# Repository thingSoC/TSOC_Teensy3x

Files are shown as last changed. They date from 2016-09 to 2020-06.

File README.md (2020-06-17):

# TSOC_Teensy3x

The **TSOC_Teensy3x** is an adapter board for the excellent [Teensy Development Board](https://www.pjrc.com/teensy/) from [PJRC](https://www.pjrc.com/).

The **TSOC_Teensy3x** allows you to connect [thingSoC](http://thingsoc.github.io/), [Mikrobus](http://www.mikroe.com/mikrobus/), 
and/or [Grove System](http://www.seeedstudio.com/blog/2016/03/09/tutorial-intro-to-grove-connectors-for-arduinoraspberry-pi-projects/) 
Modules all at the same time, either standalone, or with any other thingSoC Processor or Radio module.
This gives you maximum flexiblity for sensor and actuator selection and reuse. 

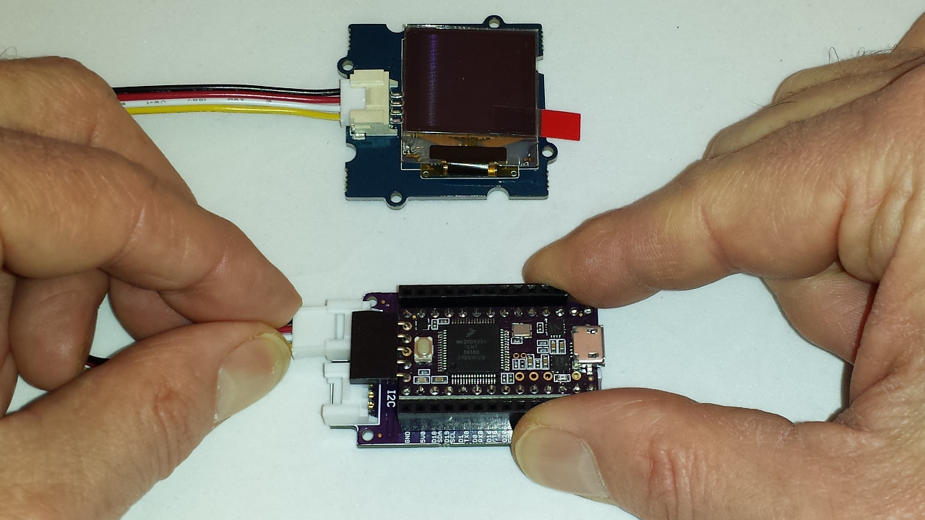
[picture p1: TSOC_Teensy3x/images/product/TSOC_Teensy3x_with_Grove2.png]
thingSoC TSOC_TEENSY3X
[TSOC_TEENSY3X](https://github.com/thingSoC/TSOC_TEENSY3X)

The thingSoC "Grovey Series" was designed as "Everyday Electronics", a no-frills, low cost, approach to modular embedded product design.
thingSoC boards are similar in size to most break-out-boards (BOBs), but feature a standardized stacking pinout, as well as an I2C metadata store (EEPROM)
to indicate what peripherals are installed.

---------------------------------------

## TSOC_TEENSY3X Application Pictures

In this example, we use the [Grovey_I2CHUB](https://github.com/thingSoC/TSOC_GROVEY_I2CHUB) with the [Teensy3.x Adapter](https://github.com/thingSoC/TSOC_Teensy3x)
to support a Grove 16x2 LCD panel.

Since the Grove 16x2 LCD panel is a 5V peripheral, the [Grovey_I2CHUB](https://github.com/thingSoC/TSOC_GROVEY_I2CHUB) performs the voltage level translation
necessary to go from the 3.3V Teensy3.x processor to the 5V LCD controller. The [Teensy3.x Adapter](https://github.com/thingSoC/TSOC_Teensy3x) also has an I2C output jack, but it is at a 3.3V level,
and so, the [Grovey_I2CHUB](https://github.com/thingSoC/TSOC_GROVEY_I2CHUB) is necessary to convert to 5V I2C outputs.

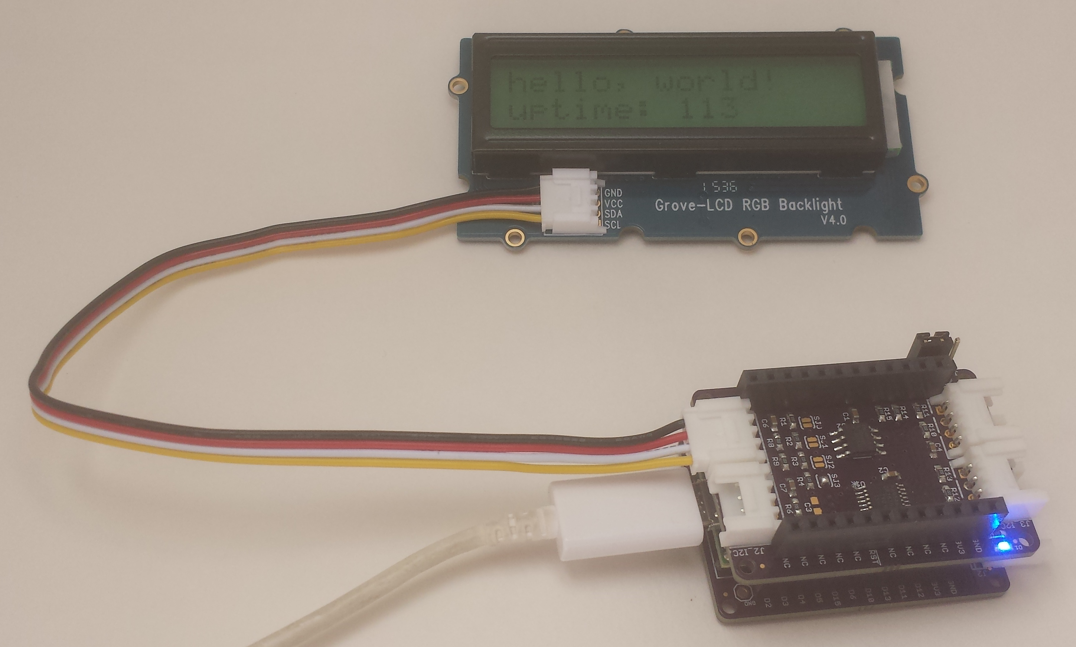
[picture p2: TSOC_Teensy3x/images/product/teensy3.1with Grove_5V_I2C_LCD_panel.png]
thingSoC TSOC_TEENSY3X
[*TSOC_TEENSY3X*](https://github.com/thingSoC/TSOC_TEENSY3X)

---------------------------------------

## TSOC_Teensy3x with Mikrobus "Click" peripherals

The [Teensy3.x Adapter](https://github.com/thingSoC/TSOC_Teensy3x) also allows you to plug in [Mikrobus](http://www.mikroe.com/mikrobus/) 
peripherals and ["Click Modules"](http://www.mikroe.com/click/), and use these along with the 
[Grove System](http://www.seeedstudio.com/blog/2016/03/09/tutorial-intro-to-grove-connectors-for-arduinoraspberry-pi-projects/) modules. 

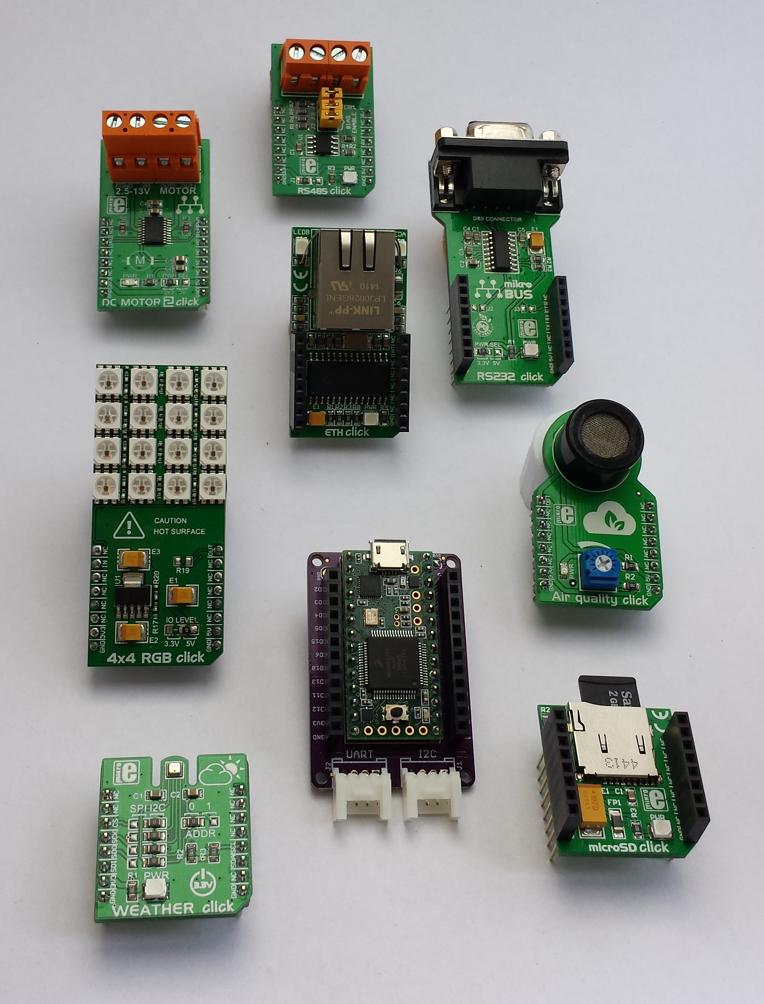
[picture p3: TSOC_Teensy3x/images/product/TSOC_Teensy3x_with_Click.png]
thingSoC TSOC_TEENSY3X
[*TSOC_TEENSY3X*](https://github.com/thingSoC/TSOC_TEENSY3X)

---------------------------------------

## TSOC_TEENSY3X Arduino Sketch Examples

Under the Arduino "examples" directory are many Arduino IDE examples for using the Teensy board with Arduino IDE,
provided by [PJRC](https://www.pjrc.com/). Paul provides [setup and installation instructions](https://www.pjrc.com/teensy/tutorial.html) for the Teensy.
What the **TSOC_Teensy3x** adaptor board provides is an easy "plug-n-play" way to connect many different peripherals to the Teensy.

---------------------------------------

## TSOC_TEENSY3X Status <a name="TSOC_TEENSY3X_status"/>

**09/02/2016:** 
Revision 1.0 - Initial Layout - SPI PINS D11/D12 reversed!
Revision 2.0 - Fix SPI Pins, add Analog I/O

---------------------------------------
## TSOC_TEENSY3X Images

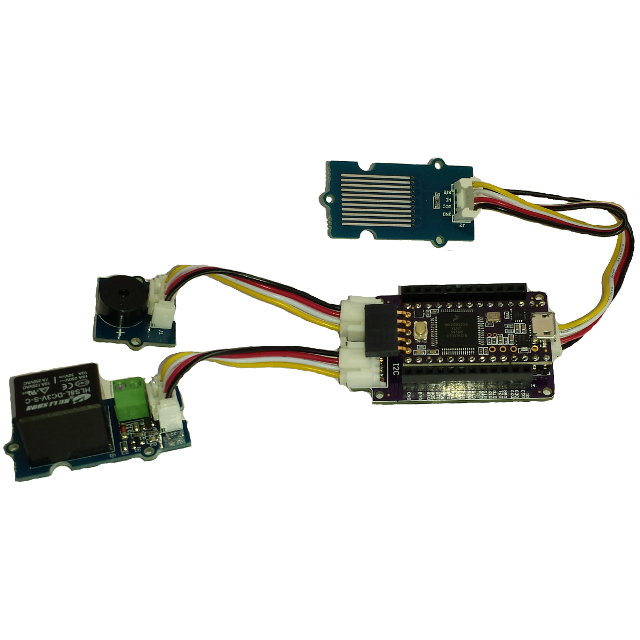
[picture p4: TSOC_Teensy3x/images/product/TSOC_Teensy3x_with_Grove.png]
thingSoC TSOC_TEENSY3X
[TSOC_TEENSY3X](https://github.com/thingSoC/TSOC_TEENSY3X)

---------------------------------------

## TSOC_TEENSY3X Documentation Index <a name="TSOC_TEENSY3X_documentation_index"/>

[TSOC_TEENSY3X Project](https://github.com/thingSoC/TSOC_Teensy3x)

[TSOC_TEENSY3X Hardware](https://github.com/thingSoC/TSOC_Teensy3x/tree/master/TSOC_Teensy3x/hardware)

---------------------------------------

## thingSoC Documentation Index <a name="thingSoC_documentation_index"/>

[thingSoC Organization Website](http://thingSoC.github.io)

[thingSoC FAQ - Frequently Asked Questions](http://thingsoc.github.io/support/faq.html)

---------------------------------------

[thingSoC 
*thingSoC*](http://thingsoc.github.io)

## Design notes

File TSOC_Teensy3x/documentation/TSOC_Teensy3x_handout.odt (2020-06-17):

thingSoC Teensy3x Board

Thank you for purchasing a TSOC_Teensy3x board!
Please see the Getting Started Guide at :
https://github.com/thingSoC/TSOC_Teensy3x (https://github.com/thingSoC/TSOC_NEOLED)
It has complete instructions and examples to download.

thingSoC Teensy3x Board

Thank you for purchasing a TSOC_Teensy3x board!
Please see the Getting Started Guide at :
https://github.com/thingSoC/TSOC_Teensy3x (https://github.com/thingSoC/TSOC_NEOLED)
It has complete instructions and examples to download.

thingSoC Teensy3x Board

Thank you for purchasing a TSOC_Teensy3x board!
Please see the Getting Started Guide at :
https://github.com/thingSoC/TSOC_Teensy3x (https://github.com/thingSoC/TSOC_NEOLED)
It has complete instructions and examples to download.

thingSoC Teensy3x Board

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

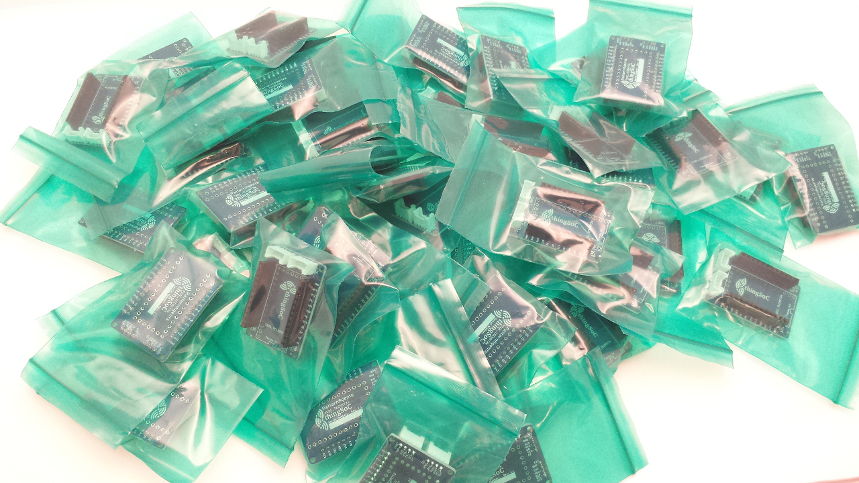
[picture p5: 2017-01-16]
TSOC_Teensy3x/images/product/teensy3x_seeed.jpg

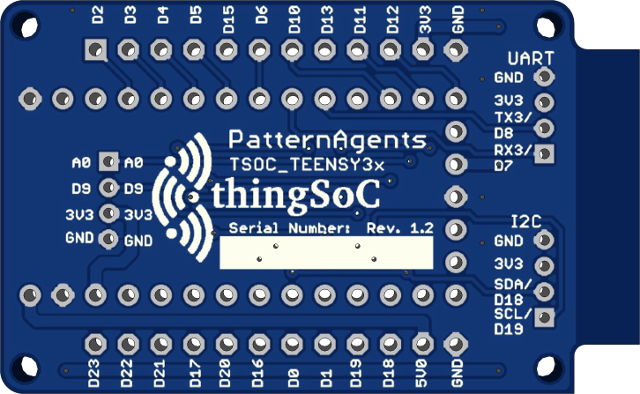
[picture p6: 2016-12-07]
TSOC_Teensy3x/images/TSOC_Teensy3x_bot.png

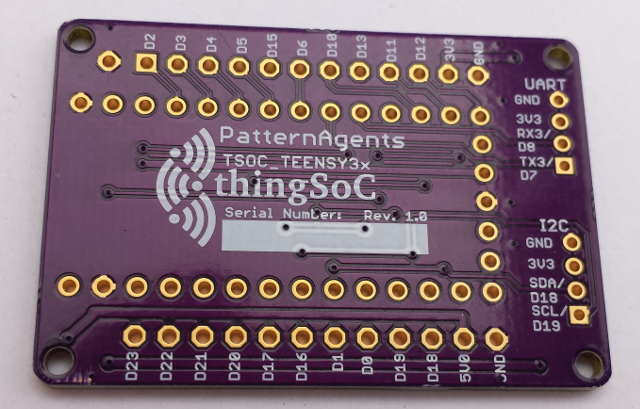
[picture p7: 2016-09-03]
TSOC_Teensy3x/images/product/TSOC_Teensy3x_pcb_bot.png

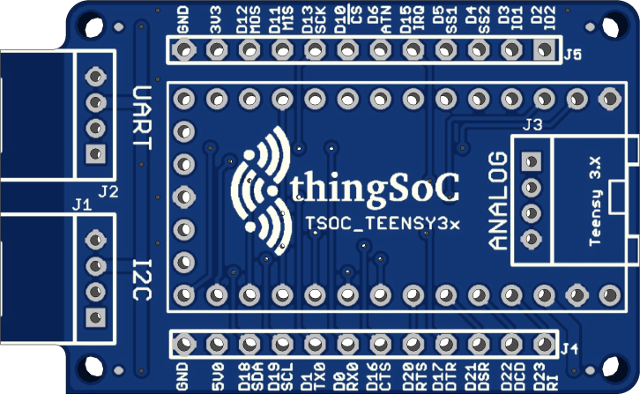
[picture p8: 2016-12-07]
TSOC_Teensy3x/images/TSOC_Teensy3x_top.png

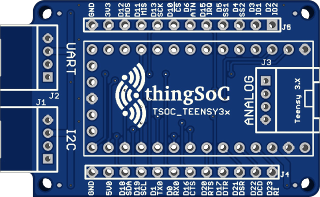
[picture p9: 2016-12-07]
TSOC_Teensy3x/images/TSOC_Teensy3x.png

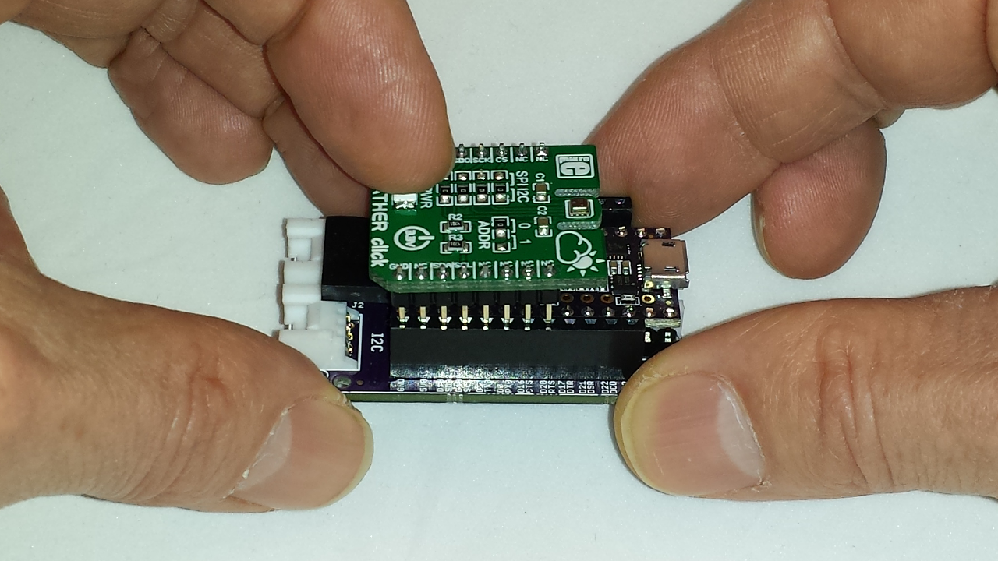
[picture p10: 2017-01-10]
TSOC_Teensy3x/images/product/TSOC_Teensy3x_with_Click2.png

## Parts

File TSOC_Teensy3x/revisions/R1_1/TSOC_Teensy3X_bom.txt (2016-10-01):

Partlist exported from U:/PatternAgents/eagle/TSOC_Modules/TSOC_Teensy3x/TSOC_Teensy3x/TSOC_Teensy3X.sch at 9/3/2016 11:11:48 AM

Revision 1.1

Qty Value             Device                      Package          Parts                  Description                                                                                                                                    
2   4P-2.0            GROVE-CONNECTOR-DIP(4P-2.0) HW4-2.0          J1, J2                 320110033                                                                                                                                      
2   M12               12 Pin, 2.54mm spacing,     M12              J3,J4

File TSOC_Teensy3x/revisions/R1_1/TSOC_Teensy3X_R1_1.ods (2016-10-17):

Qty | Value | Device | Package | Parts | Description | BOM | Seeed# | Digikey# | Digikey $/ea | MOQ | # have
1 | TSOC-PCB-SINGLE | TSOC-PCB-SINGLE | TSOC-BB-BRD-DIM | PCB | thingSoC PCB Outlines | PCB |  |  | $4.00
2 | F13X1 |  | F13x1 |  | Teensy (13) Pin Socket | OPTIONAL
2 | F12X1 | CONN HEADER FEM 12POS.1' SGL TIN | F12X1 |  | ThingSoC (12) Pin Socket | OPTIONAL |  | S6100-ND | 0.98 | 1 | 12
2 | 4P-2.0 | GROVE-CONNECTOR-DIP(4P-2.0) | HW4-2.0 | J1, J2 | Grove (4) Pin Socket | OPTIONAL | 320110033 |  | $0.15
1 | JMP-2-NC | JMP-2-NC | JMP-2-NC | 3V3 | Two Terminal Jumper - Normally Closed | EXCLUDE
1 |  | WPAD-1-PTH | WPAD-1-PTH-2.54 | GND | Wire Pad - Single | EXCLUDE

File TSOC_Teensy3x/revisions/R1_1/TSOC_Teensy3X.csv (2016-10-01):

Qty | Value | Device | Package | Parts | Description | BOM | VALUE
1 |  | WPAD-1-PTH | WPAD-1-PTH-2.54 | GND | Wire Pad - Single | EXCLUDE
2 | 4P-2.0 | GROVE-CONNECTOR-DIP(4P-2.0) | HW4-2.0 | J1, J2 | 320110033 |  | 4P-2.0
4 | FIDUCIALUFIDUCIAL | FIDUCIALUFIDUCIAL | MICRO-FIDUCIAL | FID1, FID2, FID3, FID4 | Fiducial Alignment Points
1 | JMP-2-NC | JMP-2-NC | JMP-2-NC | 3V3 | Two Terminal Jumper - Normally Closed | EXCLUDE
1 | TEENSY_3.0_BASIC | TEENSY_3.0_BASIC | TEENSY_3.0_BASIC | TEENSY | Basic Teensy 3.0 with none of the 'inner' pins enabled. See '+4', 'AllAnalogPins, and 'AllPins' packages for additional pin holes, as needed."
1 | TSOC-24-BB | TSOC-24-BB | TSOC-BB-S24 | TSOC | thingSoC Twenty-Four(24) Pin Socket
1 | TSOC-LOGO-LRG | TSOC-LOGO-LRG | TSOC-LOGO-LRG | U$5 | thingSoC Logo
1 | TSOC-PCB-SINGLE | TSOC-PCB-SINGLE | TSOC-BB-BRD-DIM | U$2 | thingSoC PCB Outlines

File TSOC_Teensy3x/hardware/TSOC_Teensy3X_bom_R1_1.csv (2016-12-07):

Part/Designator | Manufacture Part Number/Seeed SKU | Quantity
J1, J2, J3 | 320110034 | 3
J4, J5 | PPTC121LFBN-RC | 2

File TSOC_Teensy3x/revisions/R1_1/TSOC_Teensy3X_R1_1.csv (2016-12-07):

Part/Designator | Manufacture Part Number/Seeed SKU | Quantity
J1, J2 | 320110033 | 2
J3, J4 | PPTC121LFBN-RC | 2

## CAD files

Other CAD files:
TSOC_Teensy3x/eagleUp/TSOC_Teensy3x.skp

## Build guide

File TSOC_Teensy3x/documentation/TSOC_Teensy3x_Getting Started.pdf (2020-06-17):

### Welcome to the thingSoC® Teensy3x Adapter Board

The TSOC_Teensy3x is an adapter for the excellent Teensy Development Board (https://www.pjrc.com/teensy/) from

### PJRC. (https://www.pjrc.com/)

The TSOC_Teensy3x allows you to connect thingSoC (http://thingsoc.github.io/) , Mikrobus (http://www.mikroe.com/mikrobus/) , and/or Grove System (http://www.seeedstudio.com/blog/2016/03/09/tutorial-intro-to-grove-connectors-for-arduinoraspberry-pi-projects/) Modules all at the same time, either standalone, or with any other thingSoC Processor or Radio module. This gives you maximum flexiblity for sensor and actuator selection and reuse.
Assembling the TSOC_Teensy3x :
If you have purchased just the adapter board by itself, you will need to do a little soldering to assemble the unit. The TSOC_Teensy3x was designed using easy to solder through-hole components, so it would be simple to assemble for even the most inexperienced user.
1) Insert male pins into the Teensy outline. MAKE SURE to put the "short side" down, into
the holes, and the "long side" of the pins on the top side, so that the Teensy has enough space to clear the "grove" connecters and solder them securely.

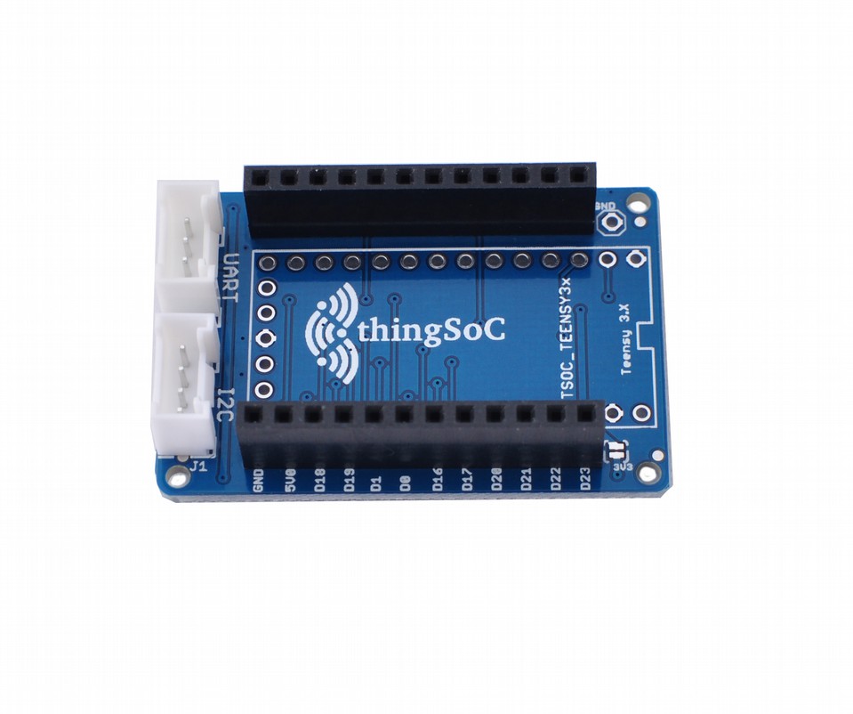
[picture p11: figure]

5) Then attach the Teensy3.2 board, and solder it securely from the top side. In the example below, we used a female connector on the end cap for access.

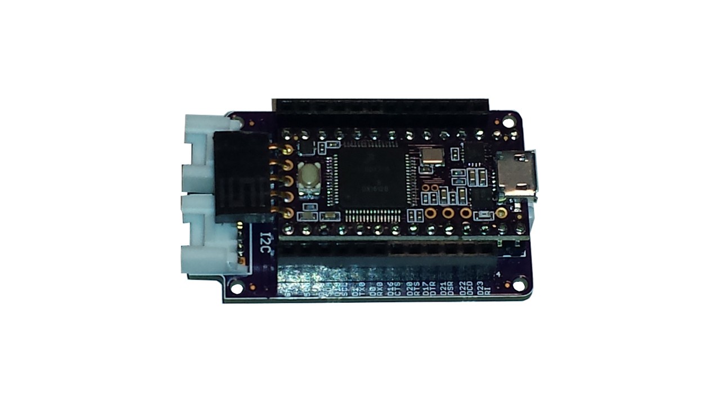
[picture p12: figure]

Download and Install Teensyduino :

Teensyduino is a software add-on for the Arduino IDE, (https://www.arduino.cc/en/Main/Software) developed for the Teensy by PJRC. (https://www.pjrc.com/teensy/td_download.html)

1) Download and install the Arduino IDE from :
https://www.arduino.cc/en/Main/Software
2) Download and install the Teensyduino package :

https://www.pjrc.com/teensy/td_download.html

3) Run the Teensyduino Installer :

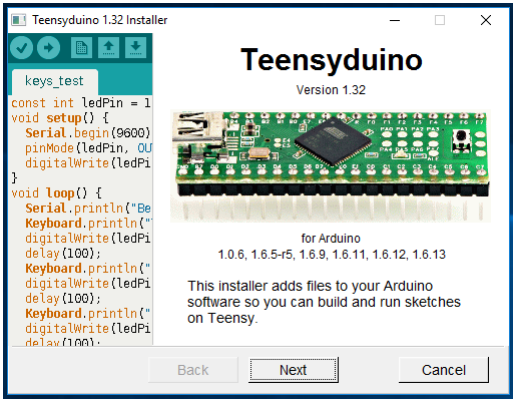
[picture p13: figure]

4) When using Arduino, be sure to select Teensy in the Tools > Boards menu.
Arduino's File > Examples menu automatically changes to show the libraries and examples for the selected board.

Getting Started :
1) Using a USB-Micro cable, plug the TSOC_Teensy3x board into your Windows, MAC, or Linux PC.
2) The drivers should be found automatically on most systems.
However if they are not, they can be downloaded from : https://www.pjrc.com/teensy/td_download.html

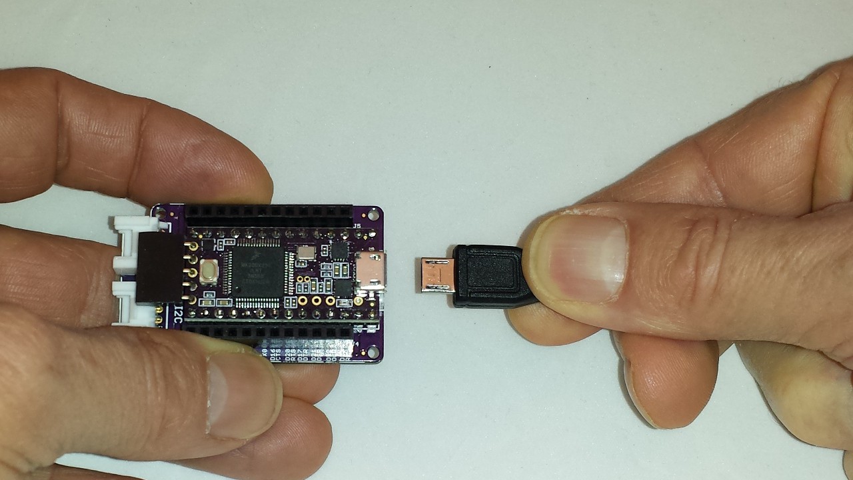
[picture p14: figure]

3) With the default firmware, when the TSOC_Teensy3x board is first connected to power, the onboard LED will begin to blink slowly.
Safe Handling Precautions :
1) Always remove/unplug all power before inserting or removing peripherals.
2) Always ground yourself by touching a ground point before handling your boards.
3) Use a static safe bag when transporting your TSOC_Teensy3x board.

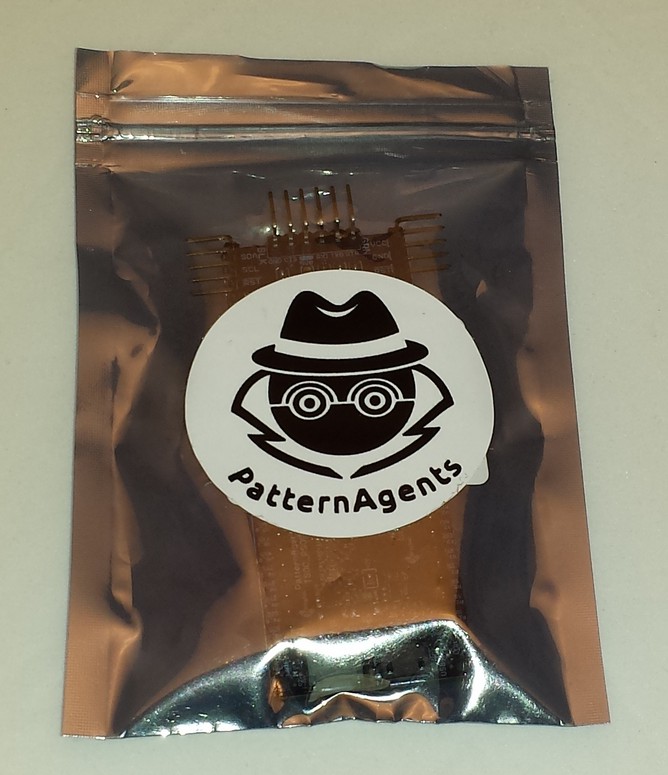
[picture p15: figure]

Supported Peripherals :
The TSOC_Teensy3x board supports thingSoC, Grove, and Mikrobus peripherals.

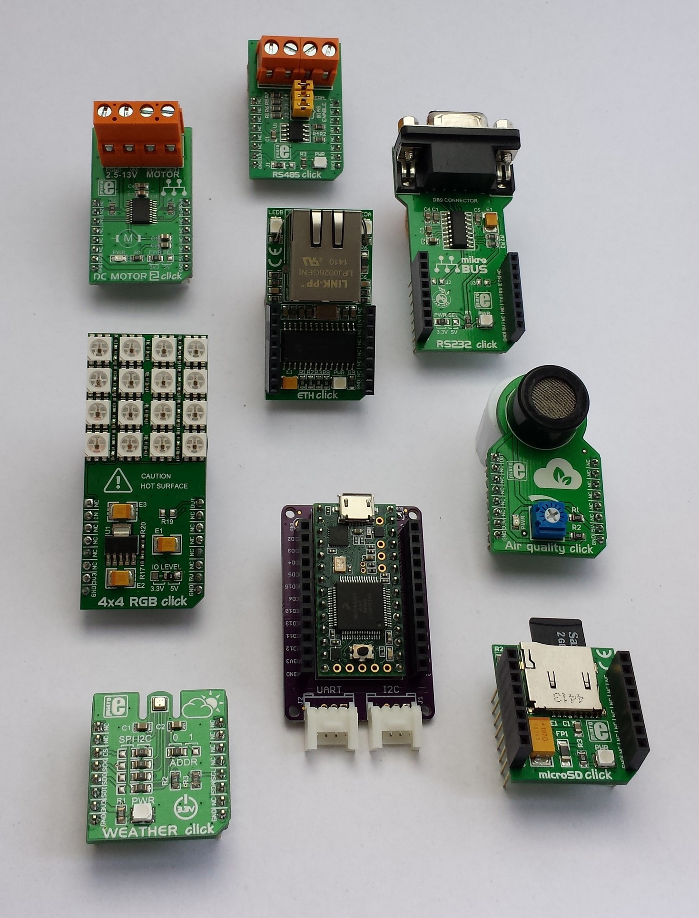
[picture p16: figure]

Attaching Mikrobus Peripherals :
1) Any 3.3 Volt compatible Mikrobus peripheral (http://download.mikroe.com/documents/standards/mikrobus/mikrobus-standard-specification-v200.pdf) may be directly connected to the TSOC_Teensy3x.
2) Make sure to align the SQUARE/CUT edges of the boards together to insure that
the polarity is correct. Push down evenly to seat the boards in the socket.
3) Note that the "stacking pins" are somewhat longer by design, and there will be some
extra space between the boards when using stacking connectors.
4) Note that Mikrobus is only sixteen (16) pins while thingSoC is twenty-four (24) pins, make sure to align the smaller Mikrobus board to the back edge of the TSOC_Teensy3x
(i.e. Ground to Ground) as shown :

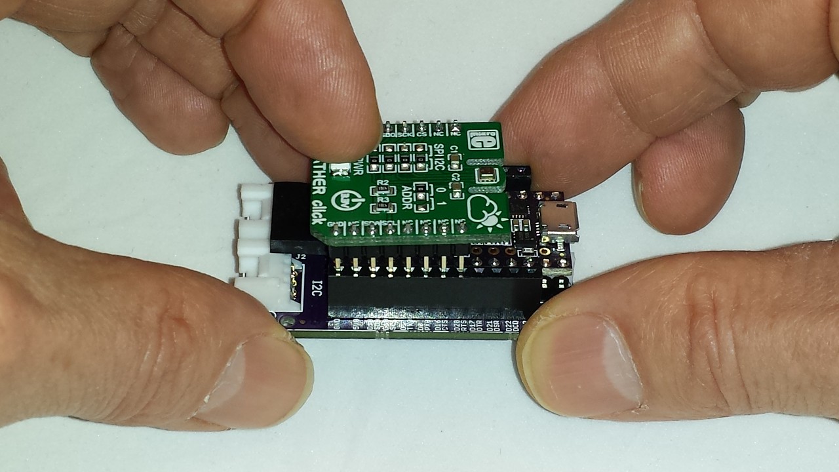
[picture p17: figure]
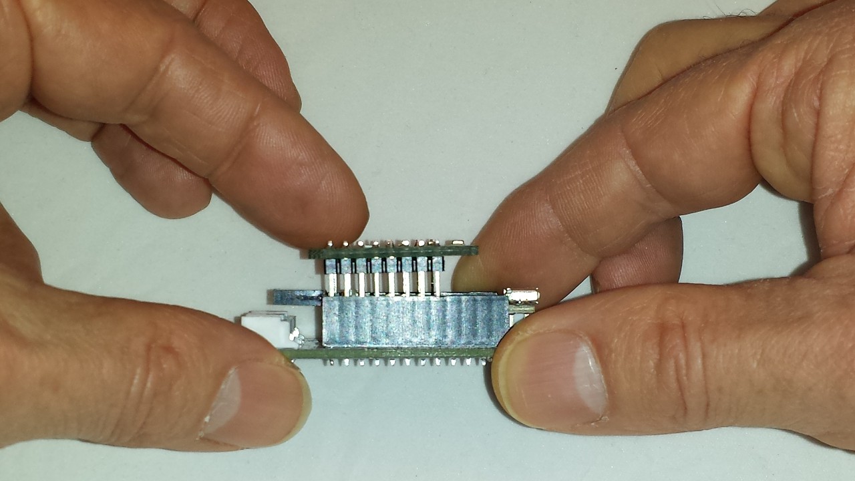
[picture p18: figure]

MikroElecktronika Click® Boards:
The TSOC_Teensy3x is compatible with most 3.3 Volt Click® boards, available at Digikey, Mouser and from Mikroelectronika direct. (https://shop.mikroe.com/click) There are already hundreds of boards available to just plug in!

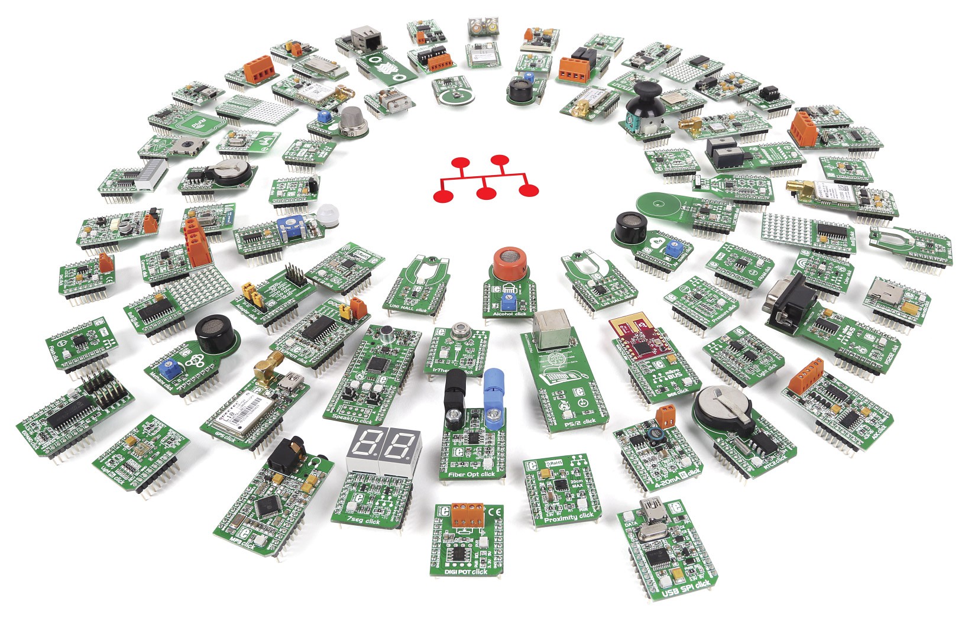
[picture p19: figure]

Attaching Grove Peripherals :
1) As shown below, there are three(3) white "Grove" connectors, and they are named, UART - (Serial #3 , using Teensy3x pins D7 and D8 )
I2C - (I2C #0, using Teensy3x pins D18 and D19 )
ANALOG - (Using Teensy3x pins A0 and D9)
Note : All of these pins are connected directly to the Teensy and are 3.3 Volt levels only.
| Do Not connect 5.0 Volt peripherals to these pins, or you may damage your Teensy! (we have the thingSoC I2C Hub, GPIO, and ADC for connecting 5.0 Volt peripherals!)

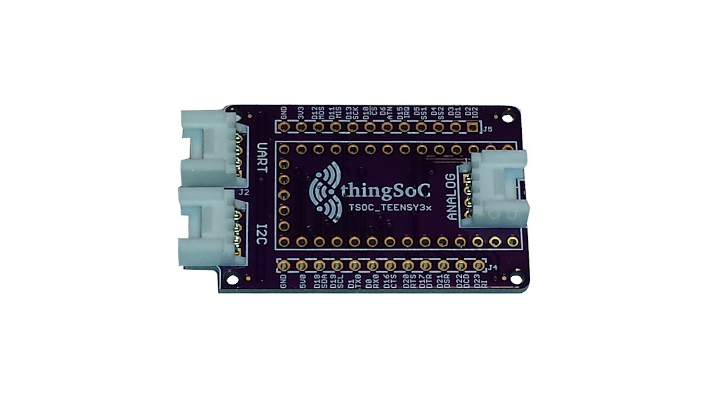
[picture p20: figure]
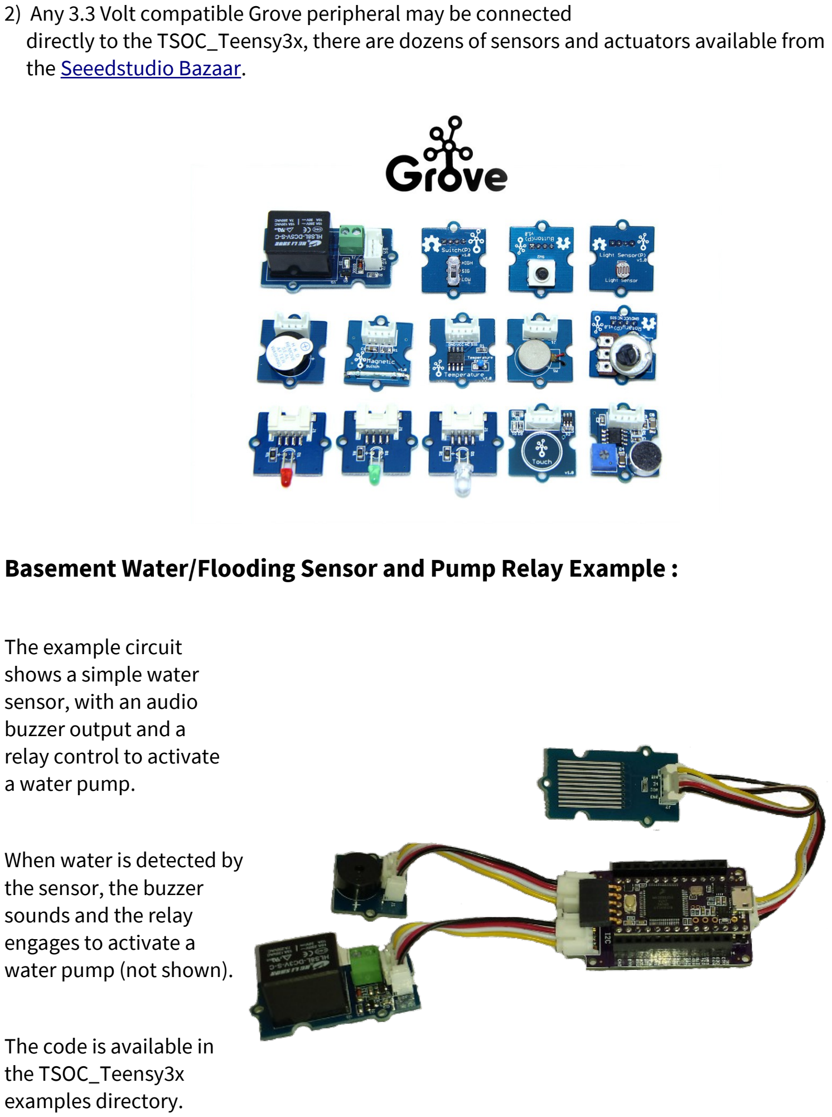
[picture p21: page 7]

2) Any 3.3 Volt compatible Grove peripheral may be connected
directly to the TSOC_Teensy3x, there are dozens of sensors and actuators available from the Seeedstudio Bazaar. (https://www.seeedstudio.com/category/Grove-c-45.html)

Basement Water/Flooding Sensor and Pump Relay Example :

The example circuit
shows a simple water
sensor, with an audio
buzzer output and a
relay control to activate
a water pump.

When water is detected by
the sensor, the buzzer
sounds and the relay
engages to activate a
water pump (not shown).

The code is available in
the TSOC_Teensy3x
examples directory.

Teensy 3.2 Features :
The TSOC_Teensy3x is a low cost, embeddable module featuring a MK20DX256VLH7 device :
- 72/96 MHZ ARM Cortex-M4F Processor (Freescale)
- USB Full-Speed Controller
- 256K Bytes Flash Memory
- 64K bytes RAM Memory
- 2048 bytes EEPROM memory
- Serial Communication (3 Ports)
- Counter/Timers/PWMs (12)
- CAN (controller area network) Controller
- I2C controllers (2)
- USER LED
- USER Pushbutton
- thingSoC Compliant Module (http://www.thingsoc.com/)
- Mikrobus Compatible Module (http://www.mikroe.com/mikrobus/)

### Top Side : (From https://www.pjrc.com/teensy/pinout.html )

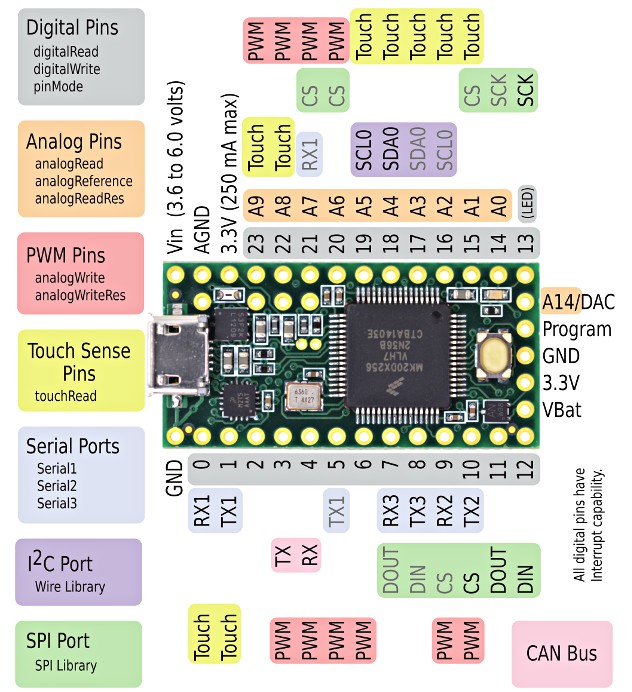
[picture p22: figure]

### Rear Side : (From https://www.pjrc.com/teensy/pinout.html )

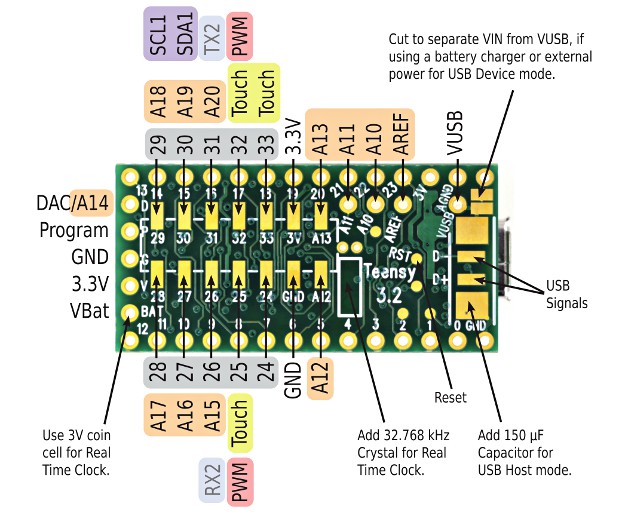
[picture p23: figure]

### thingSoC® Teensy3x Adapter Board Errata

Products Affected : Revision 1 (Blue) Boards

#1) SPI Wiring Reversed :

The initial (Rev 1) "Blue" TSOC_Teensy3x boards have the hardware SPI pins reversed, (the MISO and MOSI pins reversed). Most Arduino librarys will let you specify the SPI pins to be used explicitly, but will use software (bit-bang) SPI when you do that. Most users are able to work around this ssue. If this is a problem for your application, contact us for a Revision 2.0 board, which will be available in 3-4 weeks.

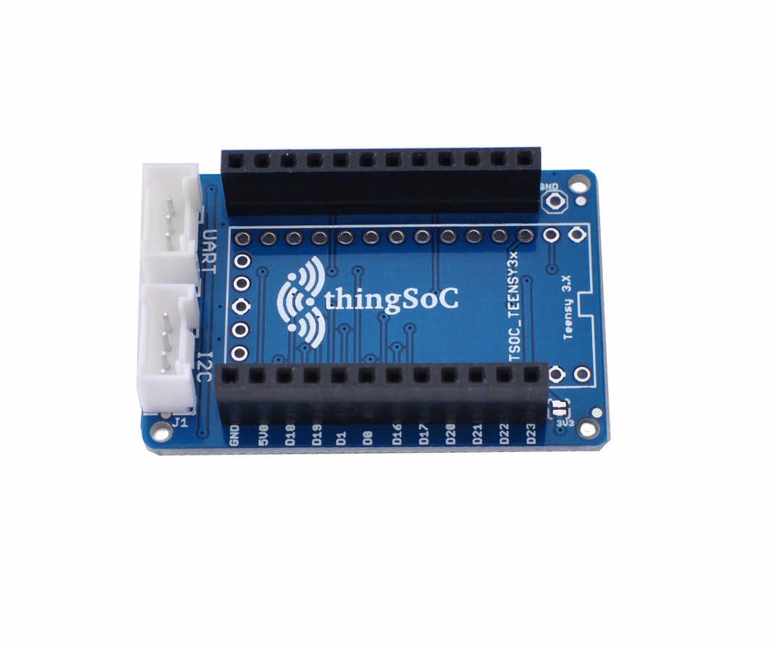
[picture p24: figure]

Revision 2.0 (Purple, Black) boards are NOT affected by Errata #1

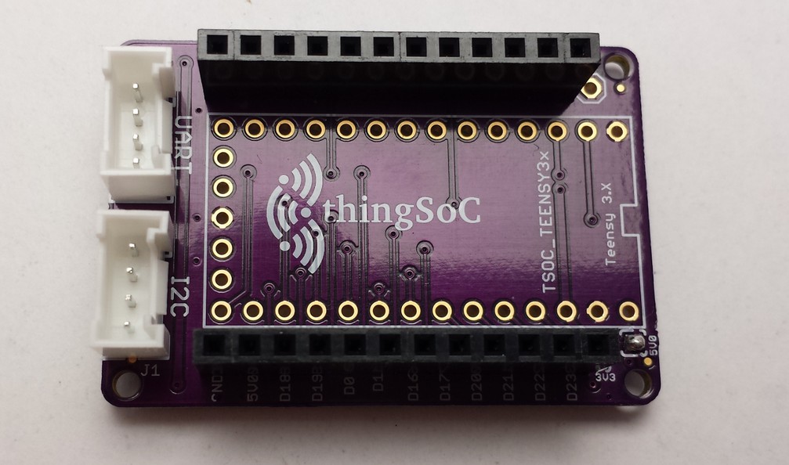
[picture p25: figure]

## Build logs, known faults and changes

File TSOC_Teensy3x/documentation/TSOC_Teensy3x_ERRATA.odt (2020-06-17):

thingSoC® Teensy3x Adapter Board Errata

The TSOC_Teensy3x is an adapter for the excellent Teensy Development Board (https://www.pjrc.com/teensy/) from PJRC (https://www.pjrc.com/).

The TSOC_Teensy3x allows you to connect thingSoC (http://thingsoc.github.io/) , Mikrobus (http://www.mikroe.com/mikrobus/) , and/or Grove System (http://www.seeedstudio.com/blog/2016/03/09/tutorial-intro-to-grove-connectors-for-arduinoraspberry-pi-projects/) Modules all at the same time, either standalone, or with any other thingSoC Processor or Radio module. This gives you maximum flexiblity for sensor and actuator selection and reuse.

Products Affected : Revision 1 (Blue) Boards

SPI Wiring Reversed :
The initial (Rev 1) "Blue" TSOC_Teensy3x boards have the hardware SPI pins reversed,
(the MISO and MOSI pins reversed). Most Arduino librarys will let you specify the
SPI pins to be used explicitly, but will use software (bit-bang) SPI when you do that.
Most users are able to work around this ssue.

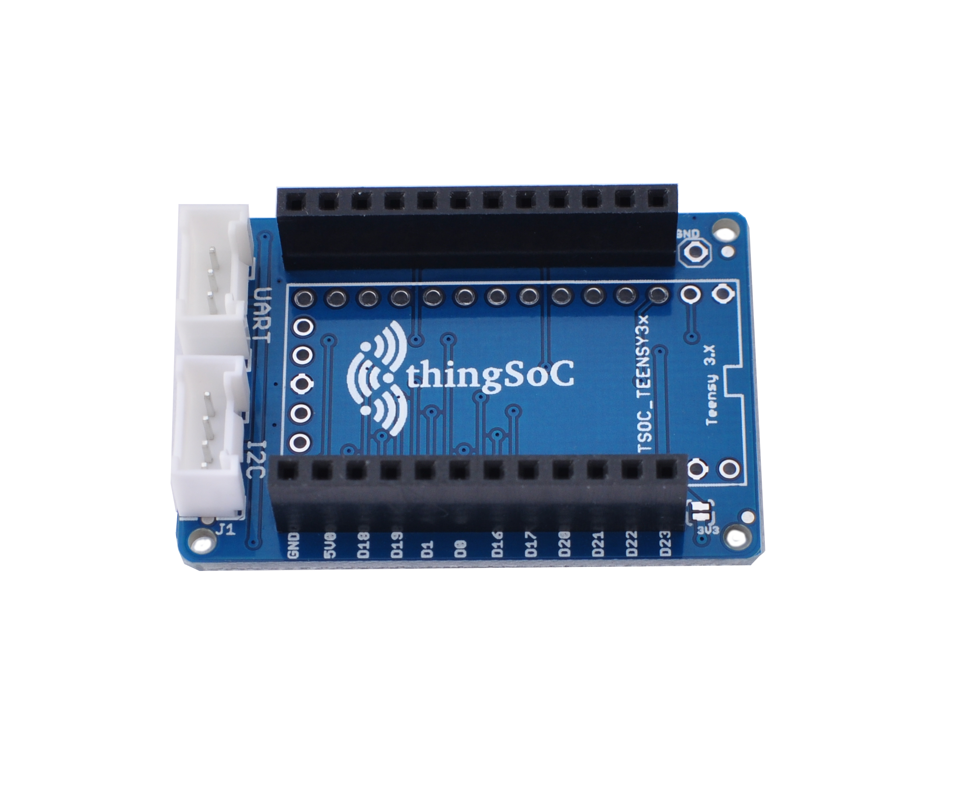
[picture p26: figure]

Revision 2.0 (Purple, Black) boards are NOT affected by Errata #1 - If this is a problem for your application, contact us for a Revision 2.0 board, which will be available in 3-4 weeks.

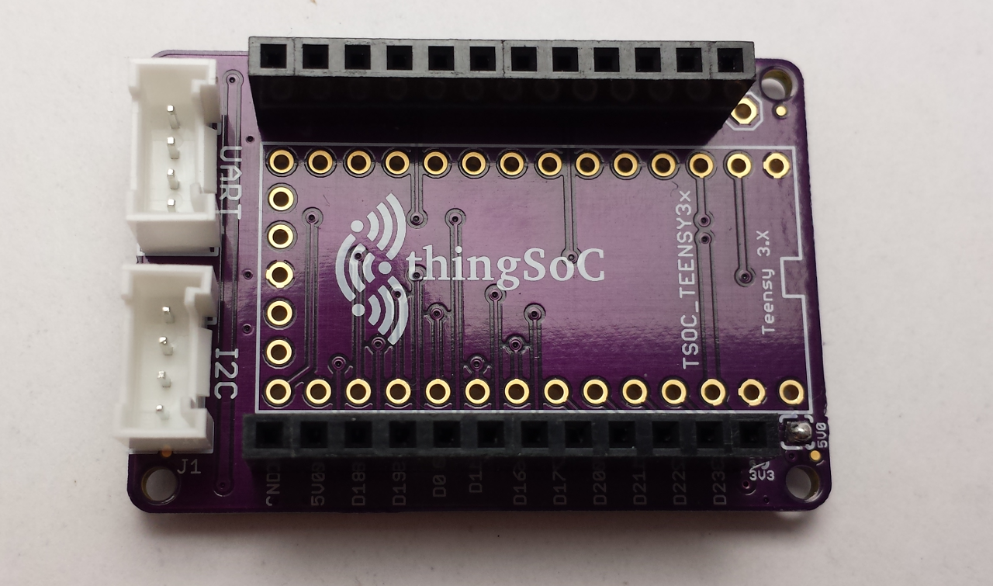
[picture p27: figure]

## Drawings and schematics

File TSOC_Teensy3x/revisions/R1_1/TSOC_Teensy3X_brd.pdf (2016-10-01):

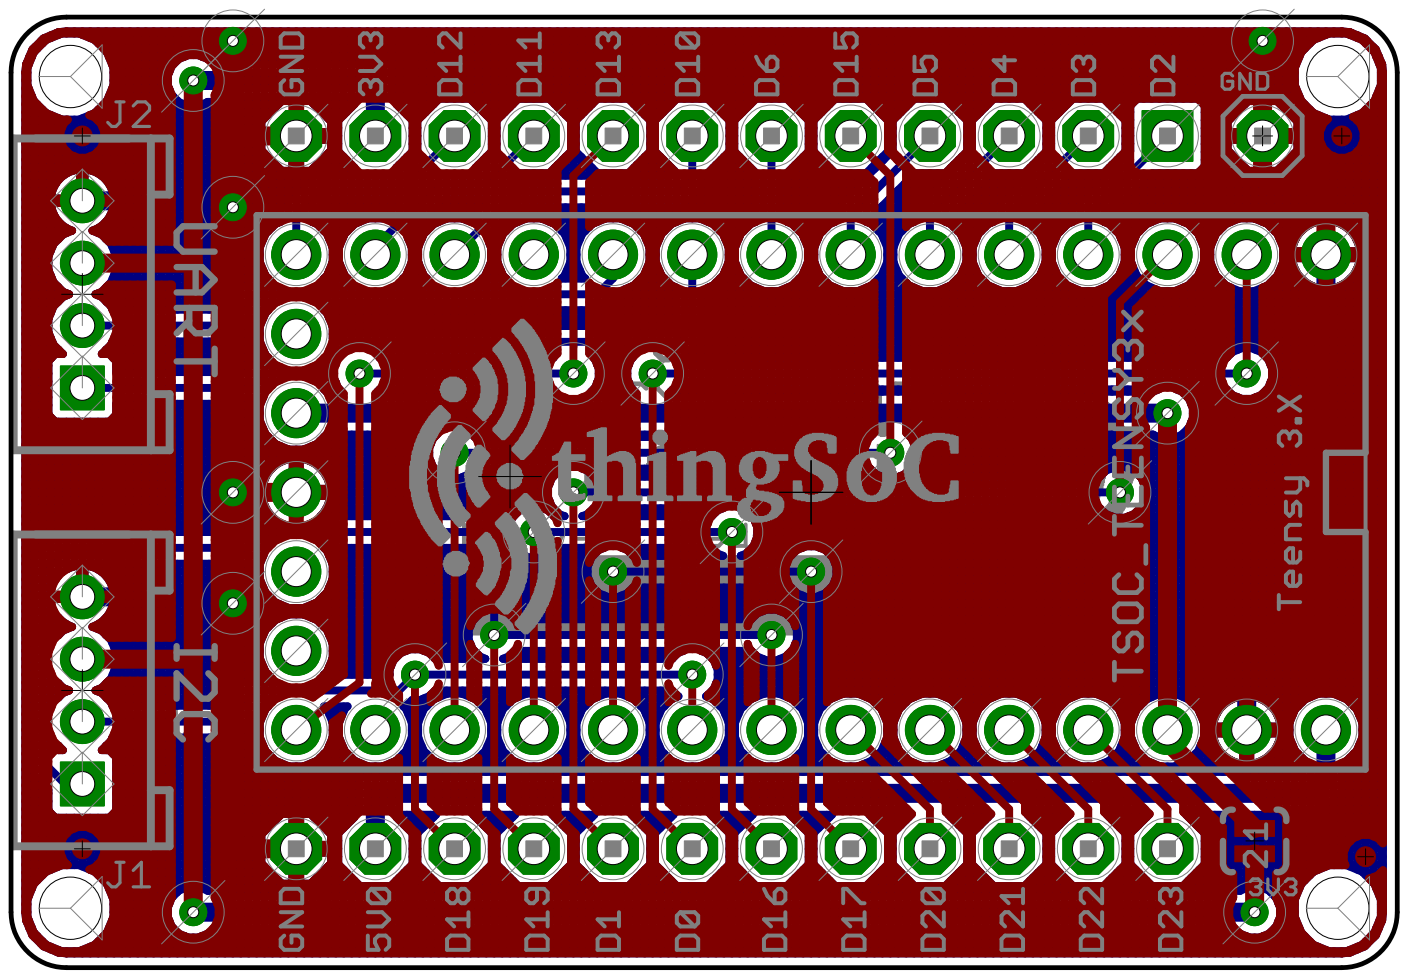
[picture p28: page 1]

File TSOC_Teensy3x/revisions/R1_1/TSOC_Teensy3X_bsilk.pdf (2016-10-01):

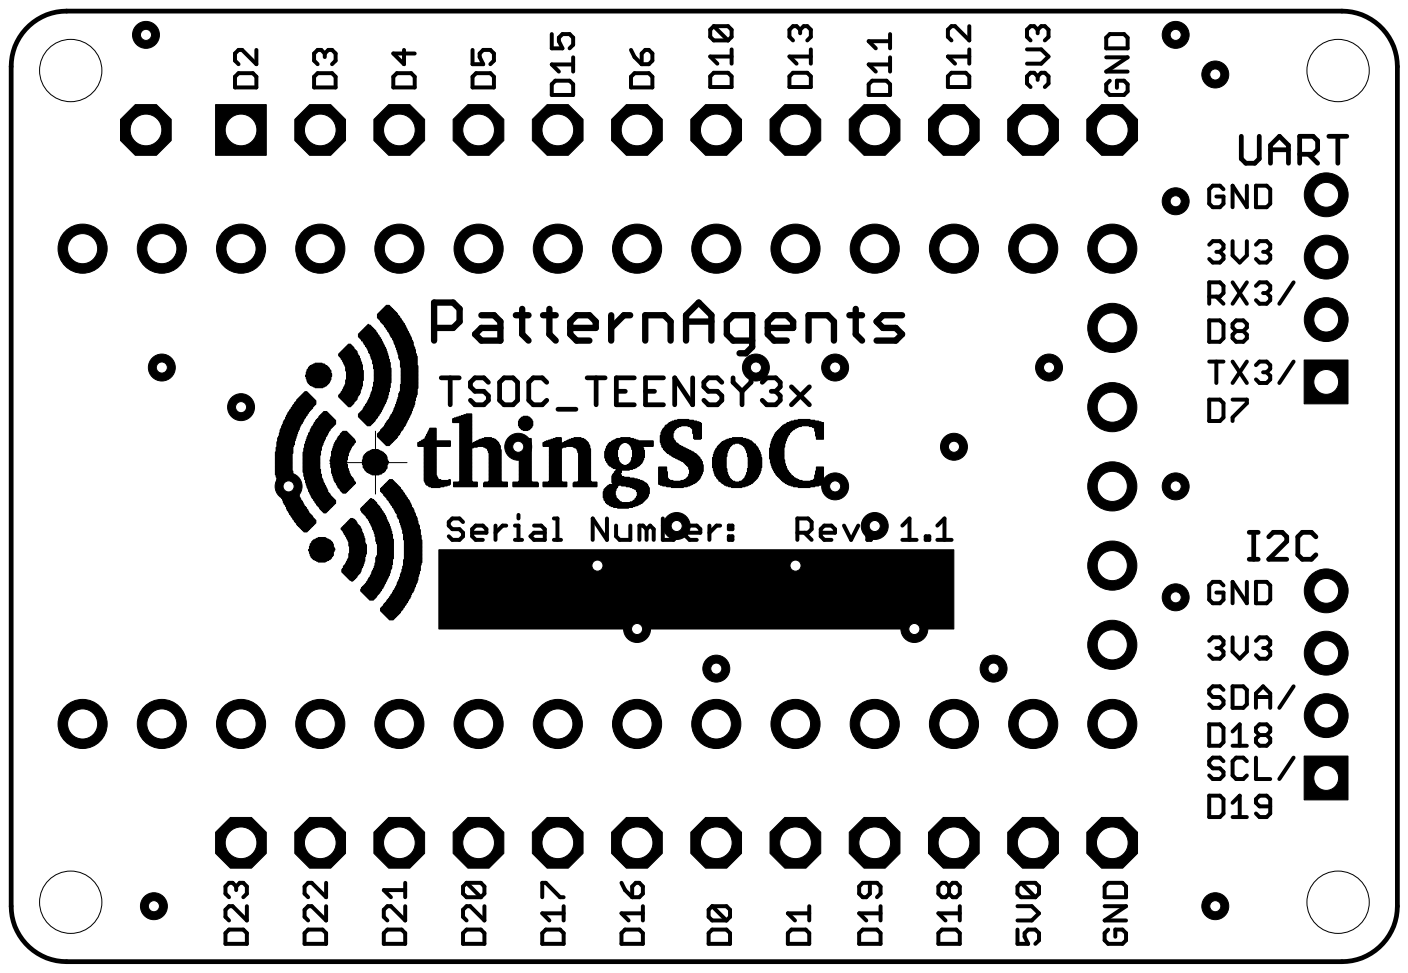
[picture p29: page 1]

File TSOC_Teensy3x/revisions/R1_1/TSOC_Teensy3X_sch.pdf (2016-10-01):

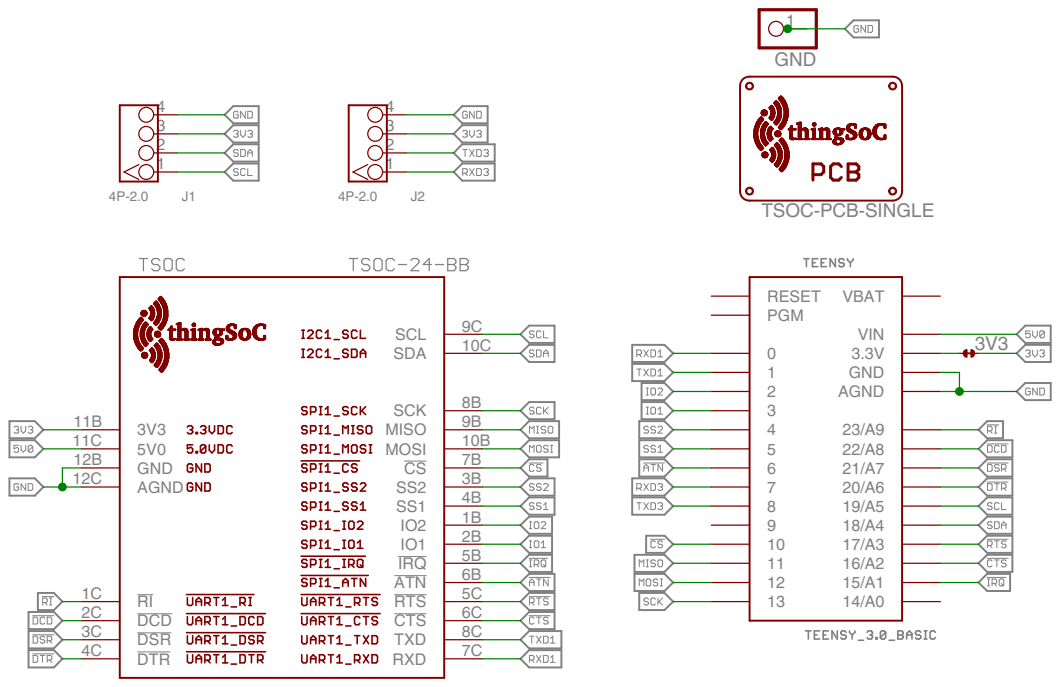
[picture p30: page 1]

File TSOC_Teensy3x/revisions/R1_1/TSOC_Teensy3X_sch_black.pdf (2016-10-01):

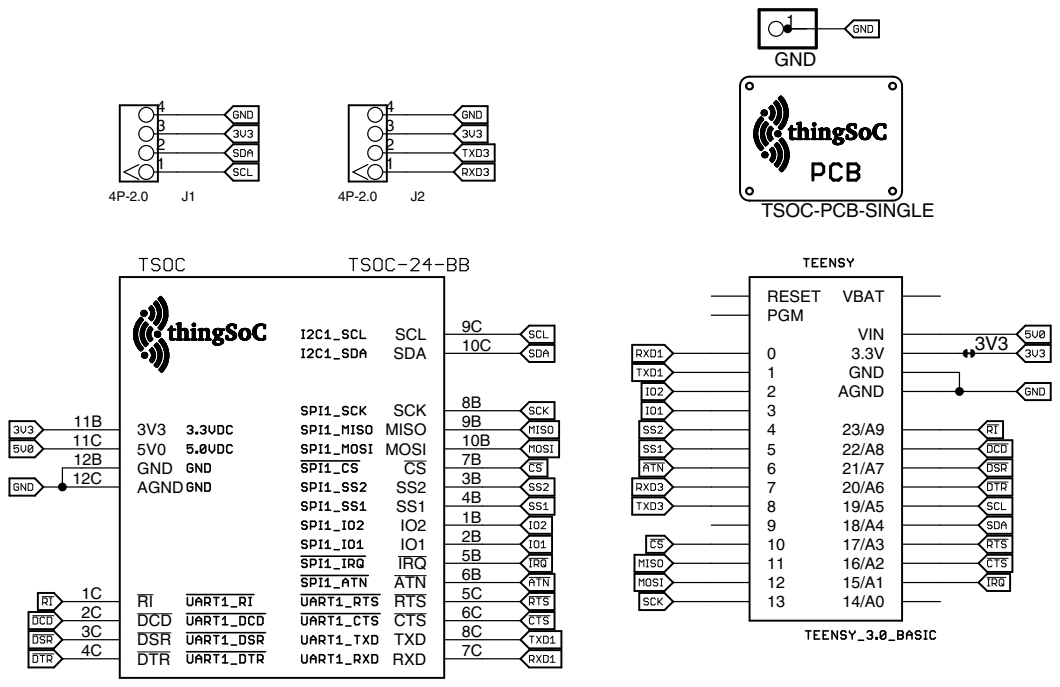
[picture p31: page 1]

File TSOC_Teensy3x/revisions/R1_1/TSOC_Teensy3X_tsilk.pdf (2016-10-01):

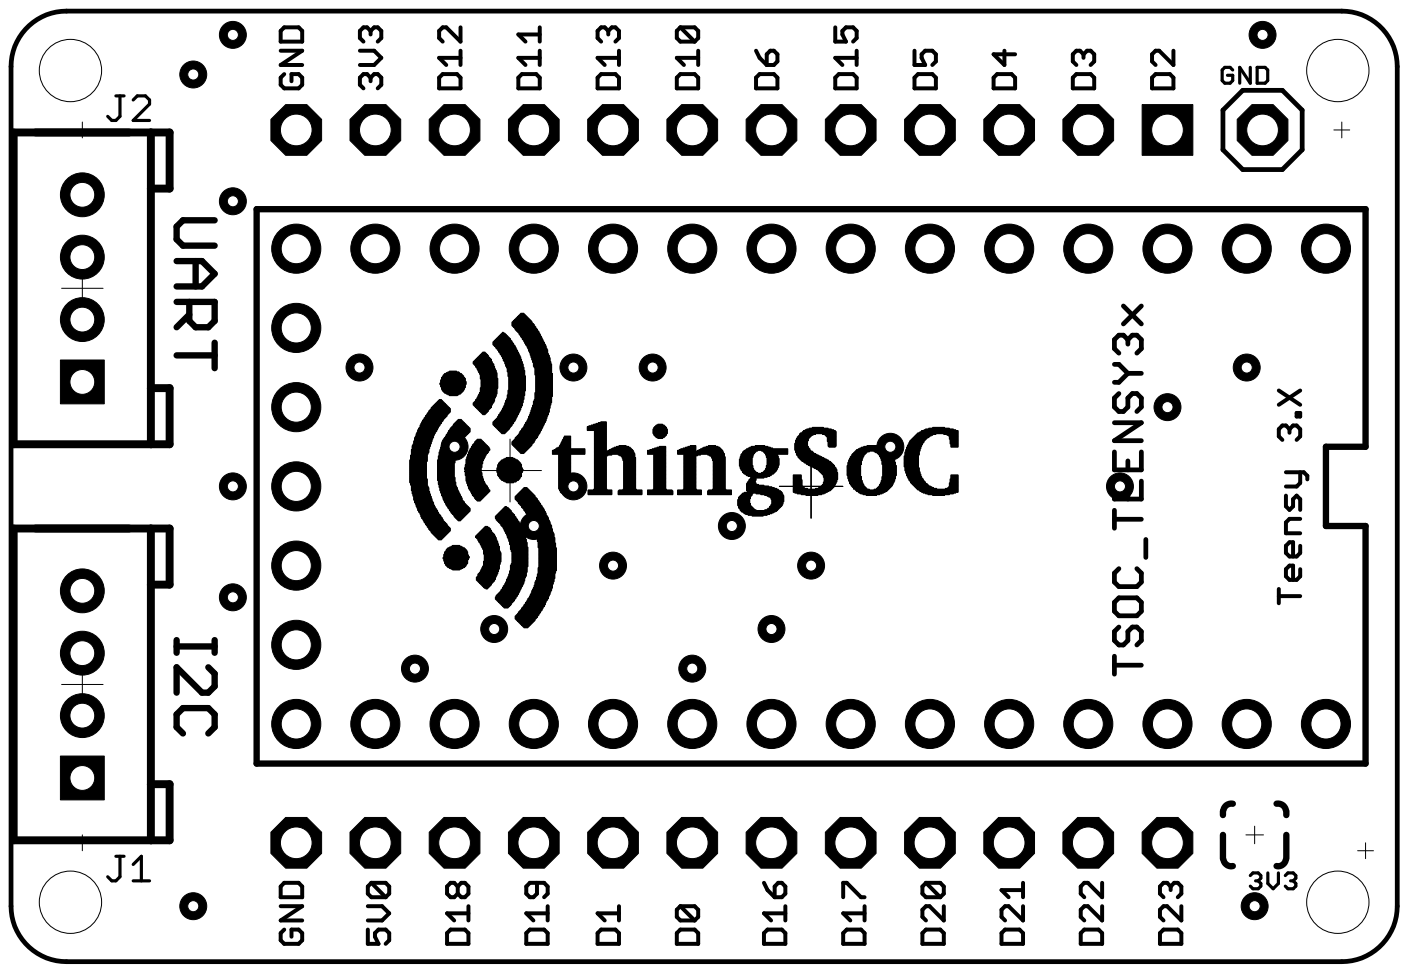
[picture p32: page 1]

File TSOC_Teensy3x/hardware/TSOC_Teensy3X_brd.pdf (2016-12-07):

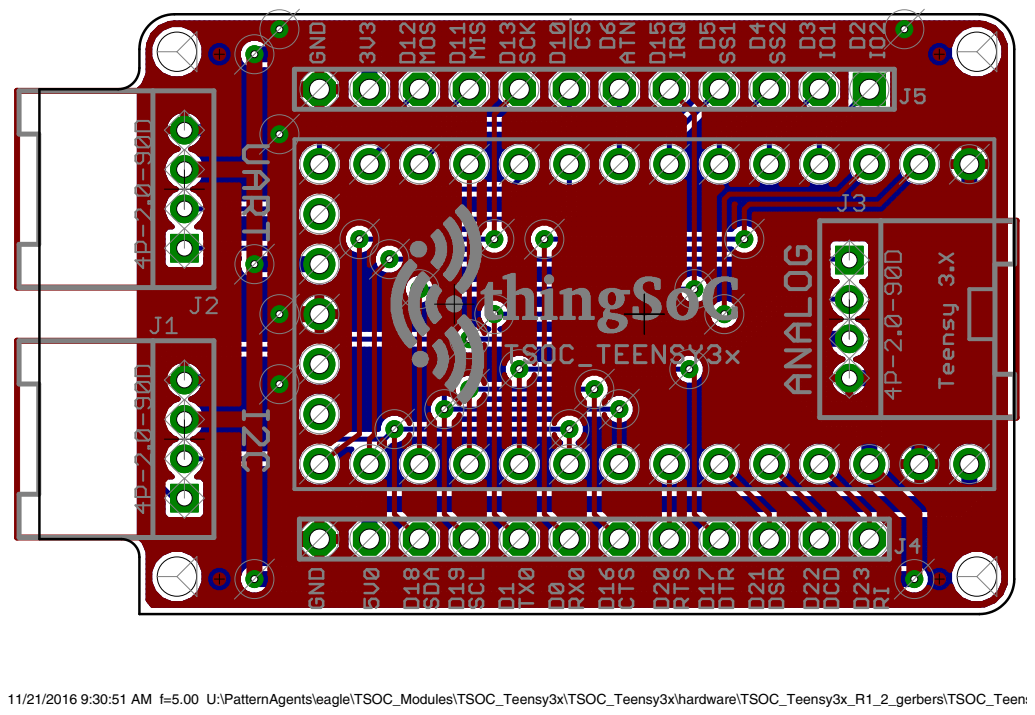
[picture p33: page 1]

11/21/2016 9:30:51 AM f=5.00 U:\PatternAgents\eagle\TSOC_Modules\TSOC_Teensy3x\TSOC_Teensy3x\hardware\TSOC_Teensy3x_R1_2_gerbers\TSOC_Teensy3X.brd

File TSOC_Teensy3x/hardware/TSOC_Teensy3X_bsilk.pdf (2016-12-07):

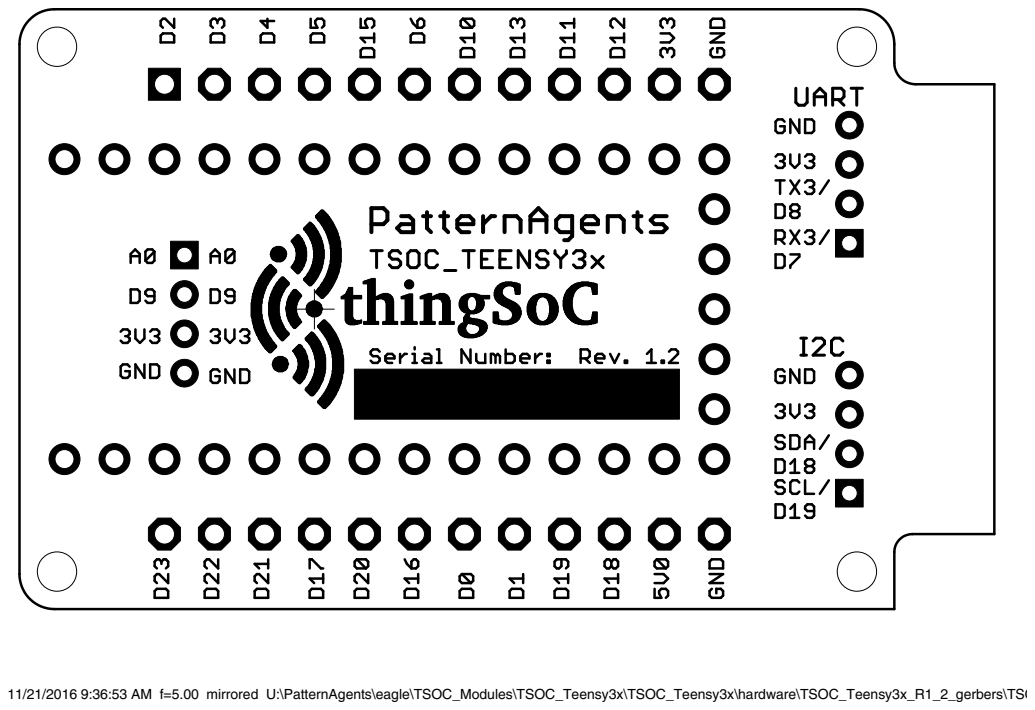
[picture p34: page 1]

11/21/2016 9:36:53 AM f=5.00 mirrored U:\PatternAgents\eagle\TSOC_Modules\TSOC_Teensy3x\TSOC_Teensy3x\hardware\TSOC_Teensy3x_R1_2_gerbers\TSOC_Teensy3X.brd

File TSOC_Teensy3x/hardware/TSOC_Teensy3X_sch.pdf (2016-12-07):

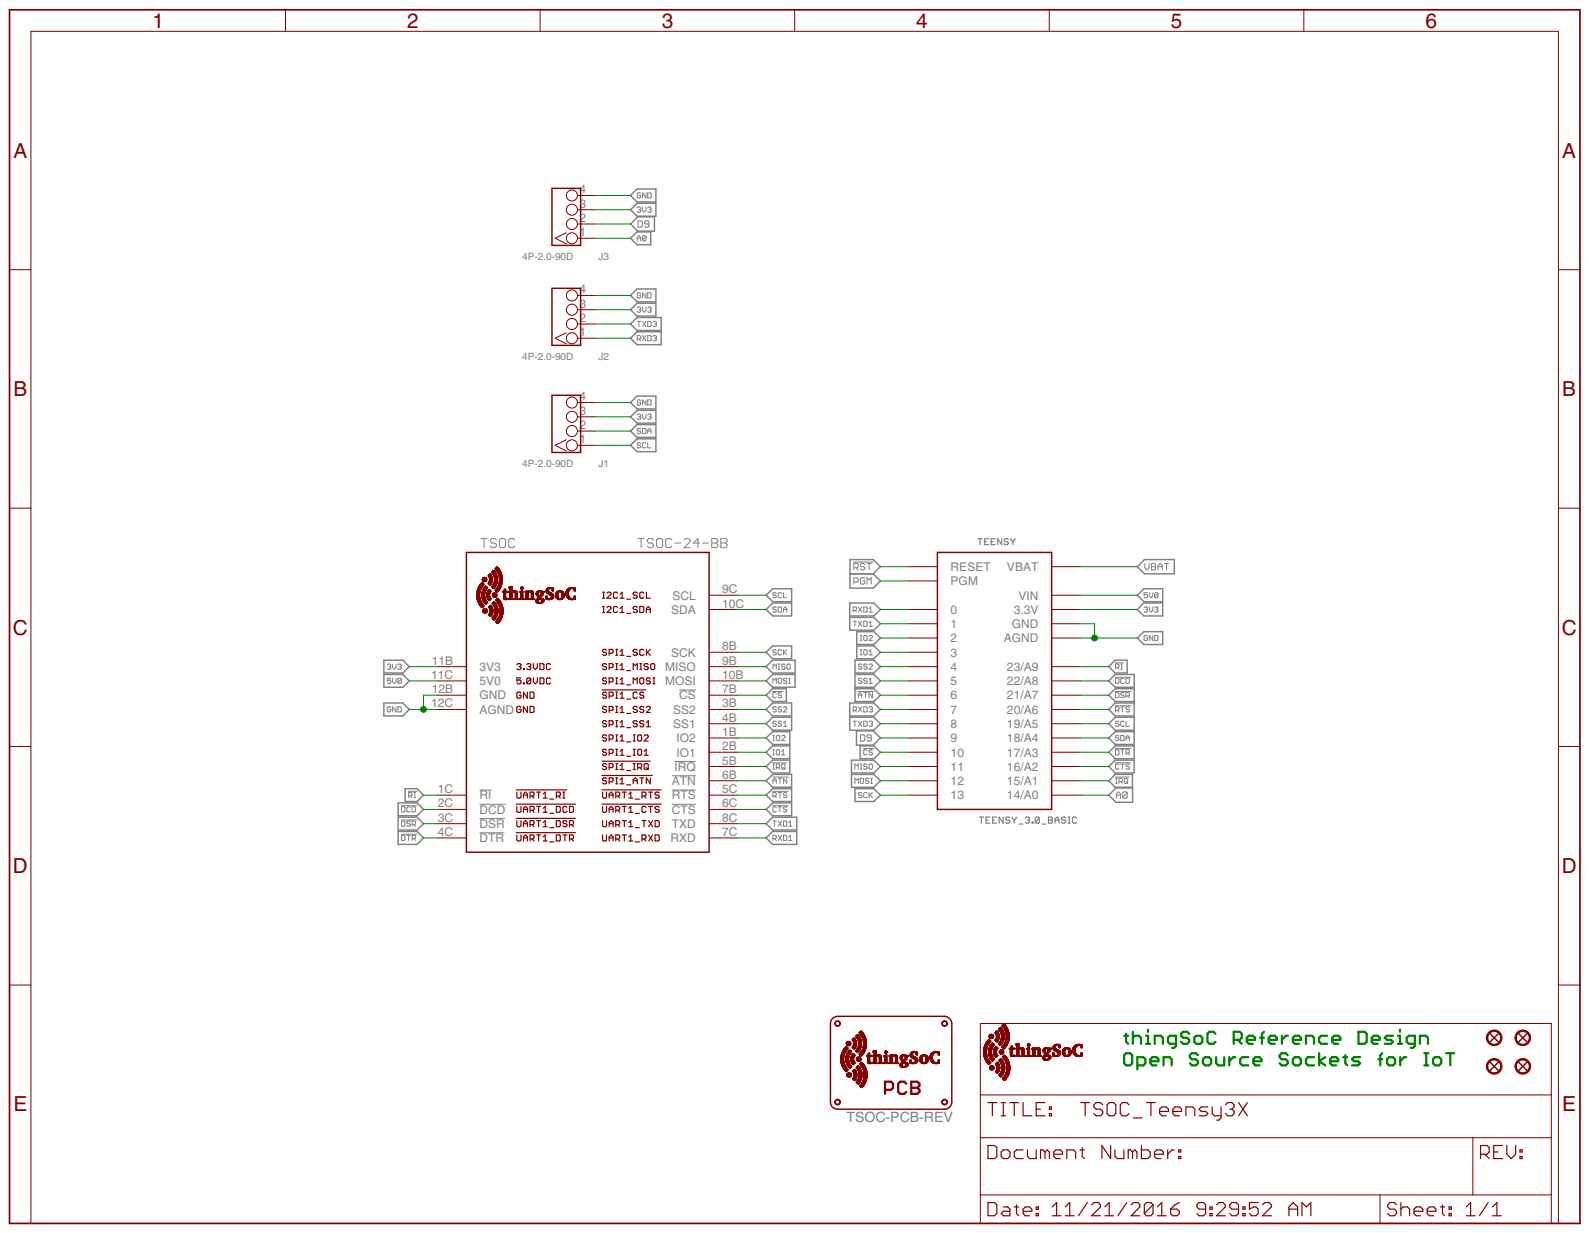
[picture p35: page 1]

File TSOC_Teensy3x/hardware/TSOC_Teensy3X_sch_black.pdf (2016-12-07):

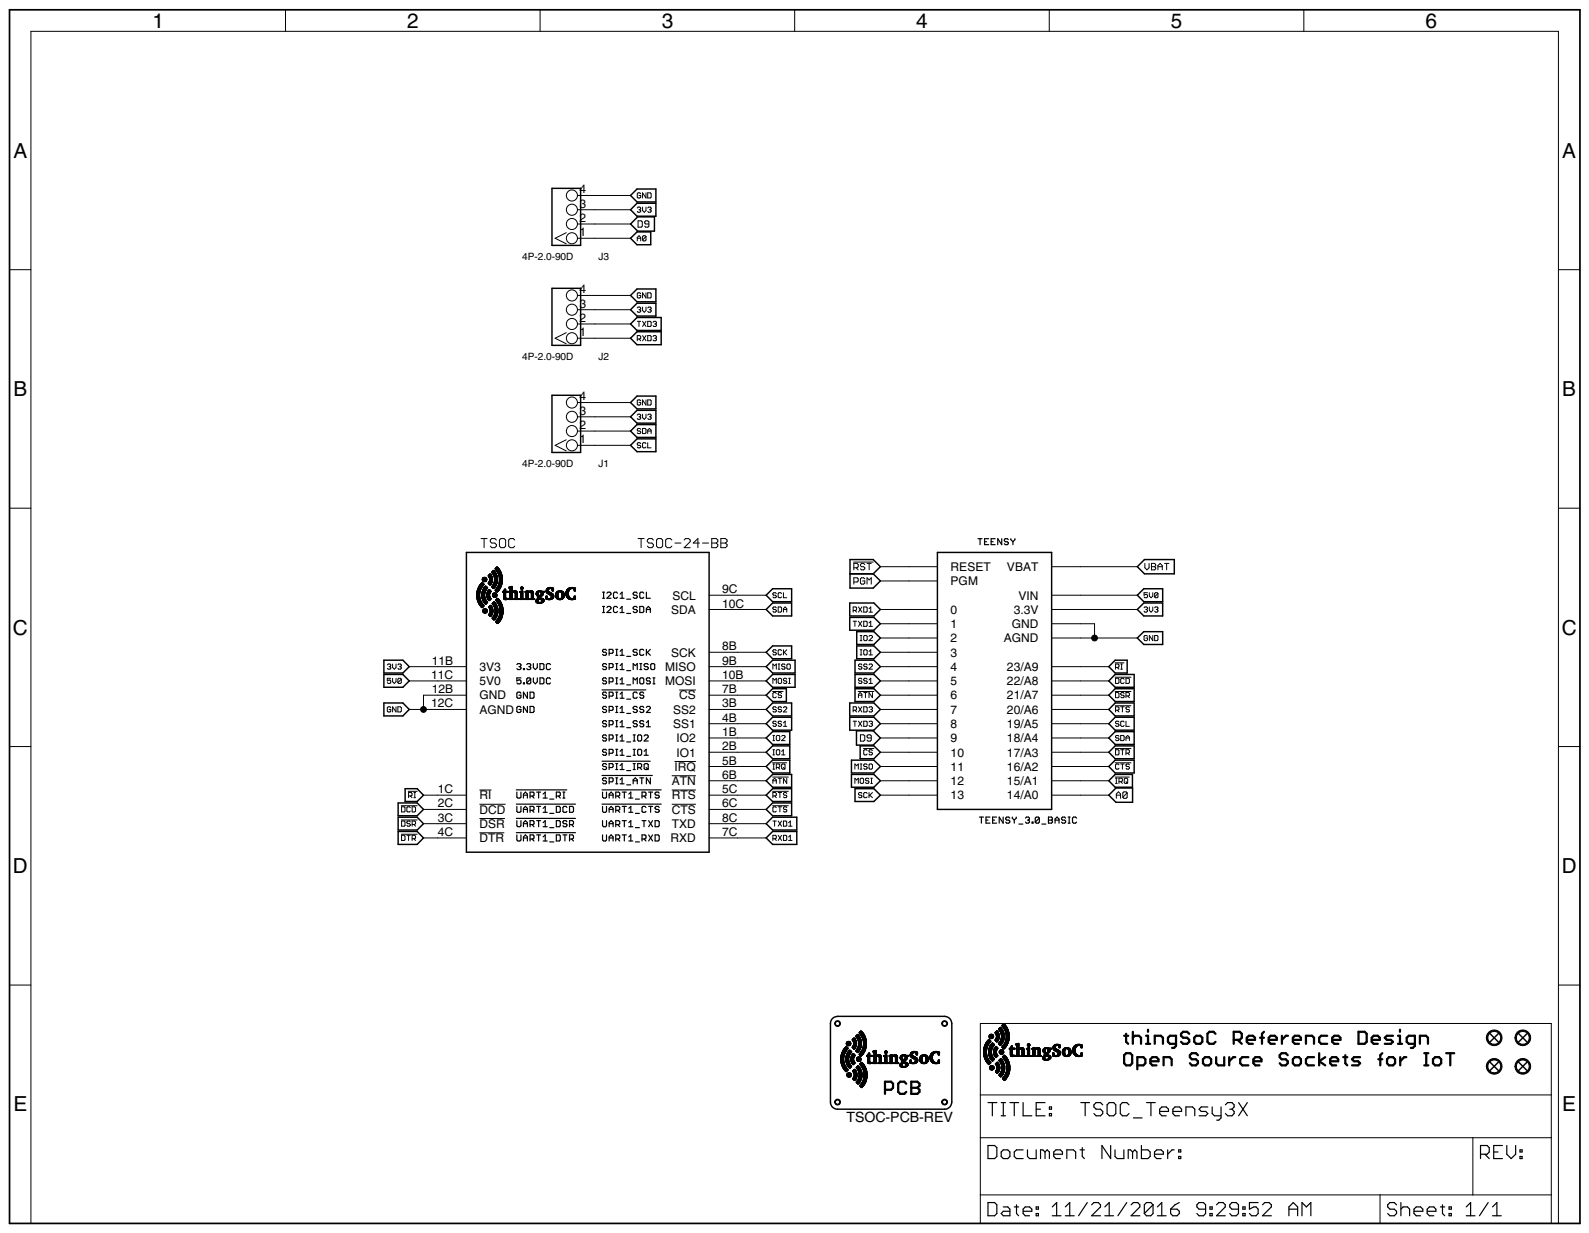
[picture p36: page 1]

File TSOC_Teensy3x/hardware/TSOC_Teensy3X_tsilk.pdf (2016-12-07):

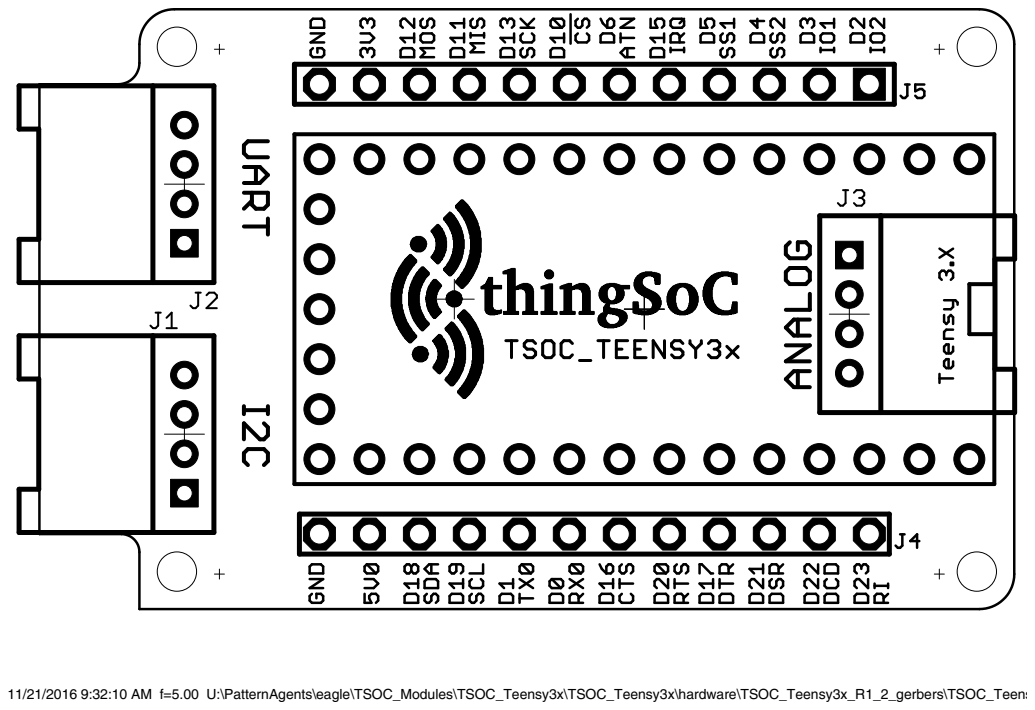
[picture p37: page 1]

11/21/2016 9:32:10 AM f=5.00 U:\PatternAgents\eagle\TSOC_Modules\TSOC_Teensy3x\TSOC_Teensy3x\hardware\TSOC_Teensy3x_R1_2_gerbers\TSOC_Teensy3X.brd

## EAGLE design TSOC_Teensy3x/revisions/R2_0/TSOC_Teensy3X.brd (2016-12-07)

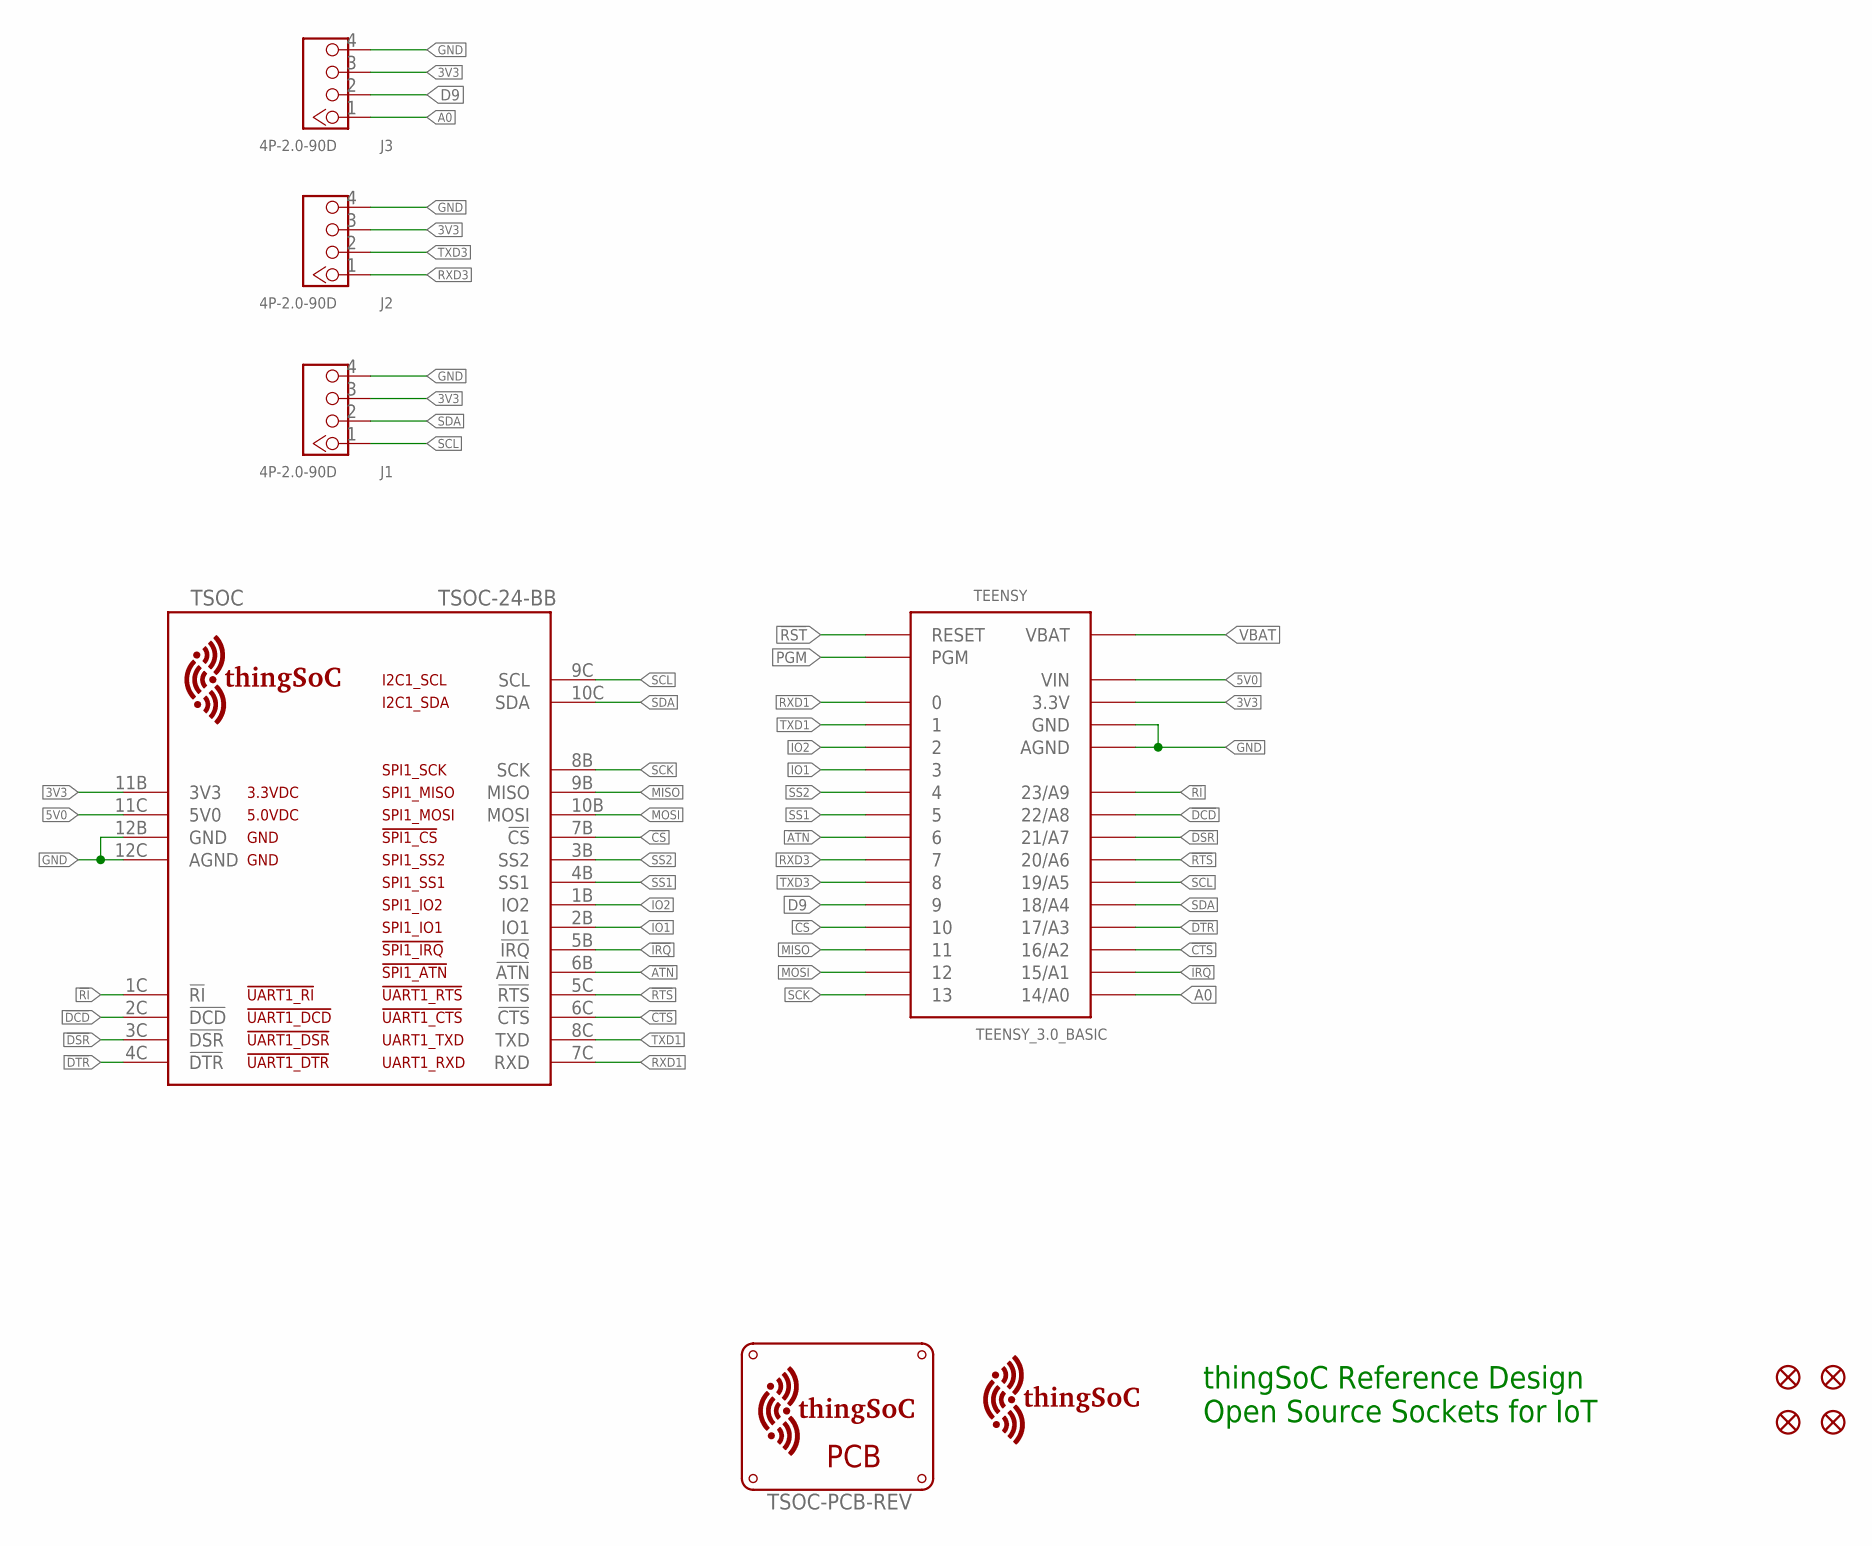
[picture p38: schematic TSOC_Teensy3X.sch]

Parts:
FID1, FID2, FID3, FID4: FIDUCIALUFIDUCIAL; MICRO-FIDUCIAL
J1, J2, J3: 4P-2.0-90D; HW4-2.0-90D
TEENSY: TEENSY_3.0_BASIC
TSOC: TSOC-24-BB; TSOC-BB-S24
U$2: TSOC-PCB-REV; TSOC-BB-BRD-PLUS-CUT-REV
U$5: TSOC-LOGO-LRG

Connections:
3V3: J1.3, J2.3, J3.3, TEENSY.3.3V, TEENSY.3.3V1 (3.3V), TSOC.11B (3V3)
5V0: TEENSY.VIN, TSOC.11C (5V0)
!ATN: TEENSY.6, TSOC.6B (!ATN)
!CS: TEENSY.10, TSOC.7B (!CS)
!CTS: TEENSY.16/A2, TSOC.6C (!CTS)
!DCD: TEENSY.22/A8, TSOC.2C (!DCD)
!DSR: TEENSY.21/A7, TSOC.3C (!DSR)
!DTR: TEENSY.17/A3, TSOC.4C (!DTR)
!IRQ: TEENSY.15/A1, TSOC.5B (!IRQ)
!RI: TEENSY.23/A9, TSOC.1C (!RI)
!RST: TEENSY.RESET
!RTS: TEENSY.20/A6, TSOC.5C (!RTS)
A0: J3.1, TEENSY.14/A0
D9: J3.2, TEENSY.9
GND: J1.4, J2.4, J3.4, TEENSY.AGND, TEENSY.GND, TEENSY.GND1 (GND), TSOC.12B (GND), TSOC.12C (AGND)
IO1: TEENSY.3, TSOC.2B (IO1)
IO2: TEENSY.2, TSOC.1B (IO2)
MISO: TEENSY.11, TSOC.9B (MISO)
MOSI: TEENSY.12, TSOC.10B (MOSI)
PGM: TEENSY.PGM
RXD1: TEENSY.0, TSOC.7C (RXD)
RXD3: J2.1, TEENSY.7
SCK: TEENSY.13, TSOC.8B (SCK)
SCL: J1.1, TEENSY.19/A5, TSOC.9C (SCL)
SDA: J1.2, TEENSY.18/A4, TSOC.10C (SDA)
SS1: TEENSY.5, TSOC.4B (SS1)
SS2: TEENSY.4, TSOC.3B (SS2)
TXD1: TEENSY.1, TSOC.8C (TXD)
TXD3: J2.2, TEENSY.8
VBAT: TEENSY.VBAT

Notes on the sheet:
thingSoC Reference Design Open Source Sockets for IoT

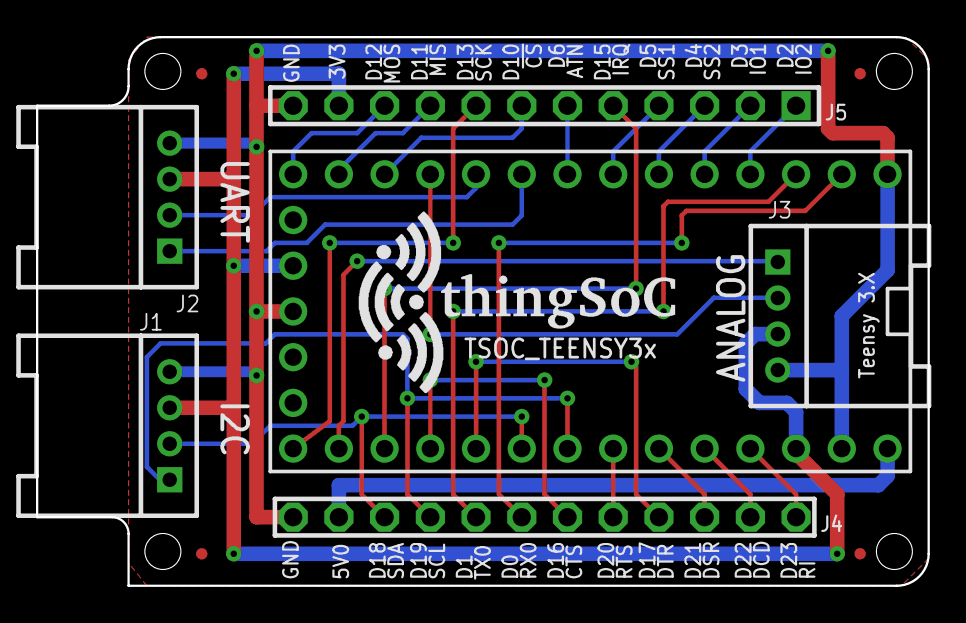
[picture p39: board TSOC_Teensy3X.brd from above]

Board: 2 copper layers, 49.5 x 30.5 mm, 12 parts (1 on the bottom side), 27 nets.

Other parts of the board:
U$1: TSOC-LOGO-LRG

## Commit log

2016-09-03 initial version
    [TSOC_Teensy3X.brd, TSOC_Teensy3X.sch]
2016-09-03 add product images
    [TSOC_Teensy3X.brd, TSOC_Teensy3X.sch, TSOC_Teensy3x.skp]
2016-10-01 update to R1.1
    [TSOC_Teensy3X.brd, TSOC_Teensy3X.csv, TSOC_Teensy3X.sch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]
2016-10-17 update BOM
    [TSOC_Teensy3X.brd, TSOC_Teensy3X.sch, TSOC_Teensy3X_R1_1.csv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]
2016-12-07 update to Rev1.2
    [TSOC_Teensy3X.brd, TSOC_Teensy3X.csv, TSOC_Teensy3X.sch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]
2017-01-10 update documentation
    [TSOC_Teensy3X.brd, TSOC_Teensy3X.sch]
2020-06-17 update to Rev2.0
    [TSOC_Teensy3X.brd, TSOC_Teensy3X.sch]

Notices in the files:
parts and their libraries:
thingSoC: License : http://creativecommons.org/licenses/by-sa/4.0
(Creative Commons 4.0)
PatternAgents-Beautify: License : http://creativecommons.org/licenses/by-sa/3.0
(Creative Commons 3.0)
